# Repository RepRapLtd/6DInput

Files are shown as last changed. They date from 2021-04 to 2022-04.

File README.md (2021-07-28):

# 6DInputs

## A Project to create open-source 3D printed 6 DoF input devices

Note  the plural ('6DInputs' and 'devices') in the headings. We would like several designs to be created here, not just one. Anyone can either contribute a new design or improve or correct an existing one.

### Development

Please fork this repository if you want to contribute, then send a pull request.

Please put your work in one of these folders, as appropriate, or create a folder under which to put the tree of your own work:

 - `Datasheets/` - useful commercial electronic or mechanical devices
 - `Electronics/` - [KiCad](https://www.kicad.org/) circuit designs
 - `Experiments/` - Results of trials and experiments
 - `Ideas/` - Thoughts and brainstorming results
 - `Inspiration/` - Related projects and other online sources of useful information
 - `Mechanics/` - Mechanical designs in [FreeCAD](https://freecadweb.org)
 - `Pictures/` - Generally useful or interestinhg images
 - `Software/` - Software for Arduino, ESP32 etc...

We would like to reserve the folder `RepRapLtd/` for our own work, so we don't get confused...

### Social media

The hashtag for this project is `#os3dmouse`.

### Licence

[GPLv3](LICENCE)

### See also

 - [HyperController](https://github.com/mnesarco/HyperController)

 - [Mighty Mouse](https://github.com/mattogodoy/mighty-mouse)

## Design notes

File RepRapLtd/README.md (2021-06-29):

# An open-source 6 degrees-of-freedom input device

[RepRap Ltd](https://reprapltd.com)

## How far have we got?

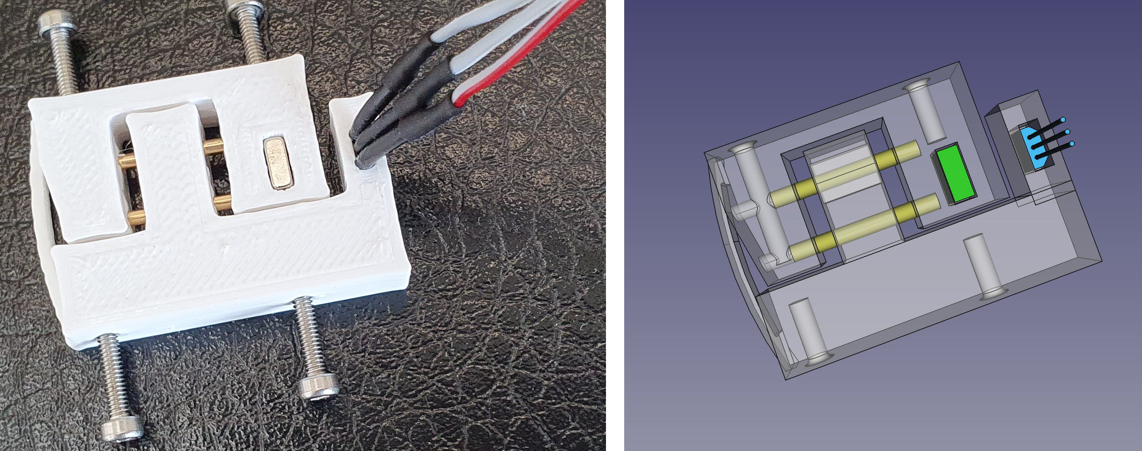
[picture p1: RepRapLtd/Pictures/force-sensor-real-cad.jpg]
Hall force sensor


Based on our [experiments on our original force-sensor design](https://github.com/RepRapLtd/6DInput/tree/main/RepRapLtd/Experiments/ForceSensor) we have created a new force sensor illustrated above.

The actual device is on the left and the FreeCAD design is on the right. It consists of a printed part with two 1.5 mm x 15 mm brass rods inserted into holes to act as sliders. On the right the magnet is shown green, and the Hall sensor is blue. The curved part at the left end of the sensor is a printed spring. The four holes in the sides allow self-tapping M2 screws to be used to attach the force sensor to whatever is pushing and pulling it. The top left screw is longer than the others as it also retains the brass rods.

The FreeCAD design is [here](https://github.com/RepRapLtd/6DInput/tree/main/RepRapLtd/Mechanics/force-sensor-V1.FCStd).

Once again, the magnets [were these](https://www.amazon.co.uk/gp/product/B00TACH0P2), and the Hall sensors were OH49E s.

This design has the following advantages:

 - It has just one integrated printed part,
 - It gives true parallel motion, with no other movement or twist possible, and
 - The additional components are cheap and easy to obtain anywhere.

## Experiments

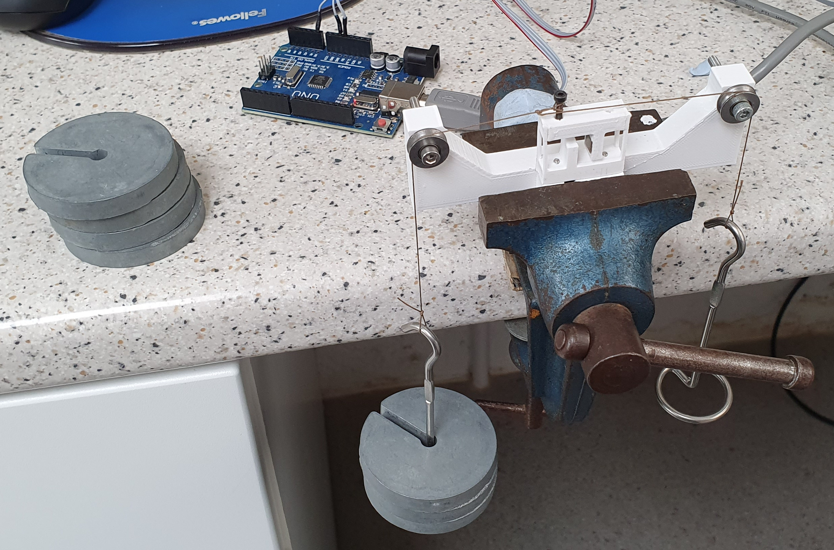
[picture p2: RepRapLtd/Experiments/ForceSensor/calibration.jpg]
force sensor test


We used a calibration jig based on our design for our first calibration experiments illustrated above. The FreeCAD file for the latest jig is in [here](https://github.com/RepRapLtd/6DInput/tree/main/RepRapLtd/Mechanics/calibration-jig.FCStd).

Here is the result of loading and unloading the device:

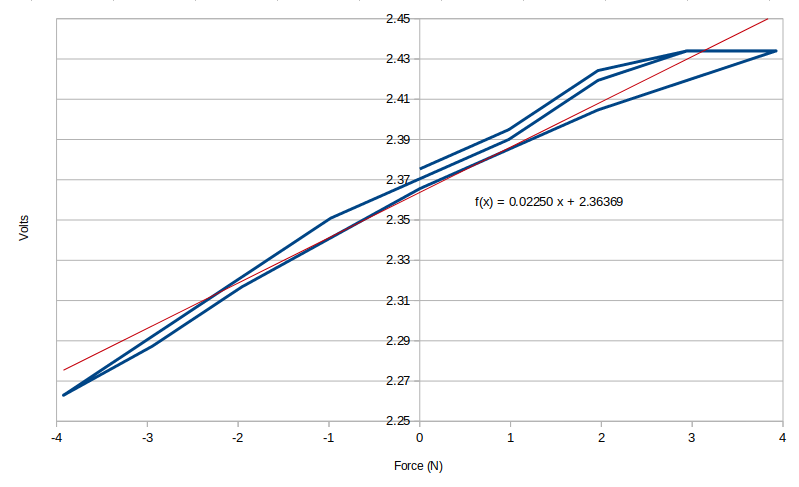
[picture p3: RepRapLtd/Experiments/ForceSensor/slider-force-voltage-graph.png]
test graph


As in our previous experiments, there is a certain amount of hysteresis, as would be expected with a plastic spring. But as you will see this does not impede the performance of the sensor. The red line is the least-squares linear fit, which has the equation shown.

We made two more sensors, giving us three in total. Then we wrote a Python program to read them and to use their output to rotate a cube about the *X, Y* and *Z* axes in 3D on the screen. This worked, and the sensor felt good in use; letting go of the sensors stopped the cube moving; pushing and pulling rotated the cube in all directions; and the harder the push or pull the faster it moved.

There is a video of this working [here](https://github.com/RepRapLtd/6DInput/tree/main/RepRapLtd/Pictures/os3dmouse.mp4) and here is a still from that:

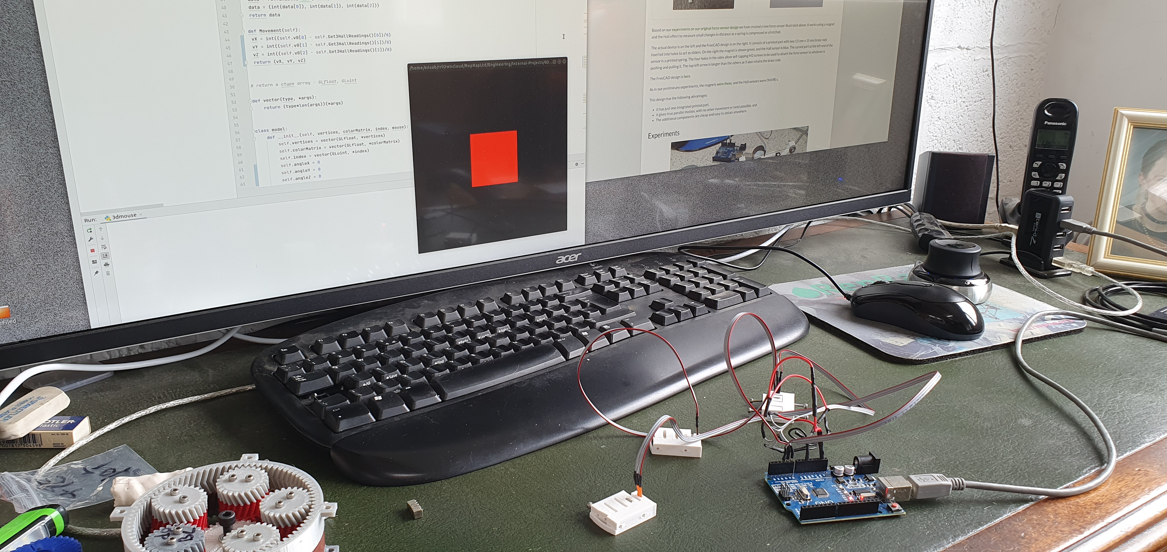
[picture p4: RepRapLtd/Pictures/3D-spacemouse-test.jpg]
1D animation


The Python program is [here](https://github.com/RepRapLtd/6DInput/tree/main/RepRapLtd/Software/3DGraphics/3dmouse.py) and the Arduino program that reads the Hall sensor and talks to the Python program is [here](https://github.com/RepRapLtd/6DInput/tree/main/RepRapLtd/Software/ArduinoHallReader/ArduinoHallReader.ino).

## Update

We realised from the success of this that it would be easy to design a 2D joystick that used the same principles.  This is the result:

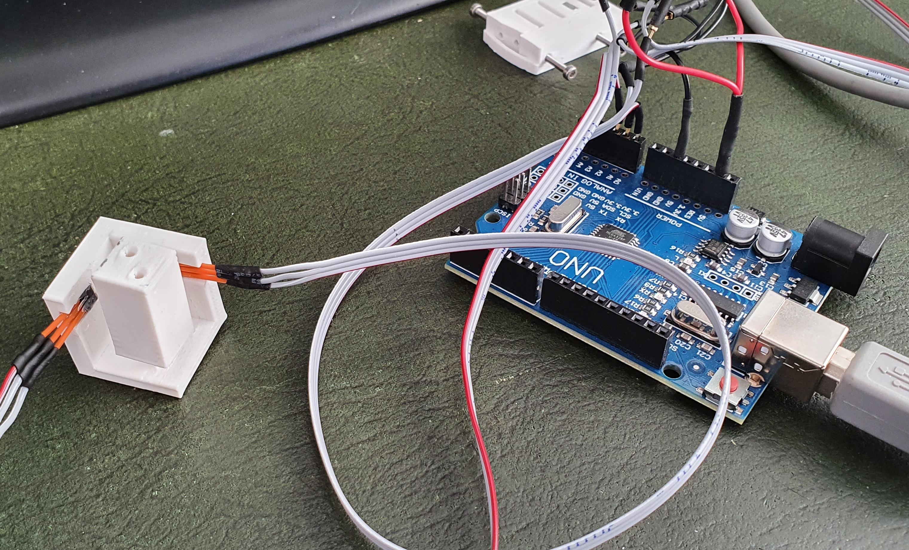
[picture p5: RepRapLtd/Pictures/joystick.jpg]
joystick


And here is the FreeCAD design (which is [here](https://github.com/RepRapLtd/6DInput/tree/main/RepRapLtd/Mechanics/2D-joystick-V1.FCStd) in the repository):

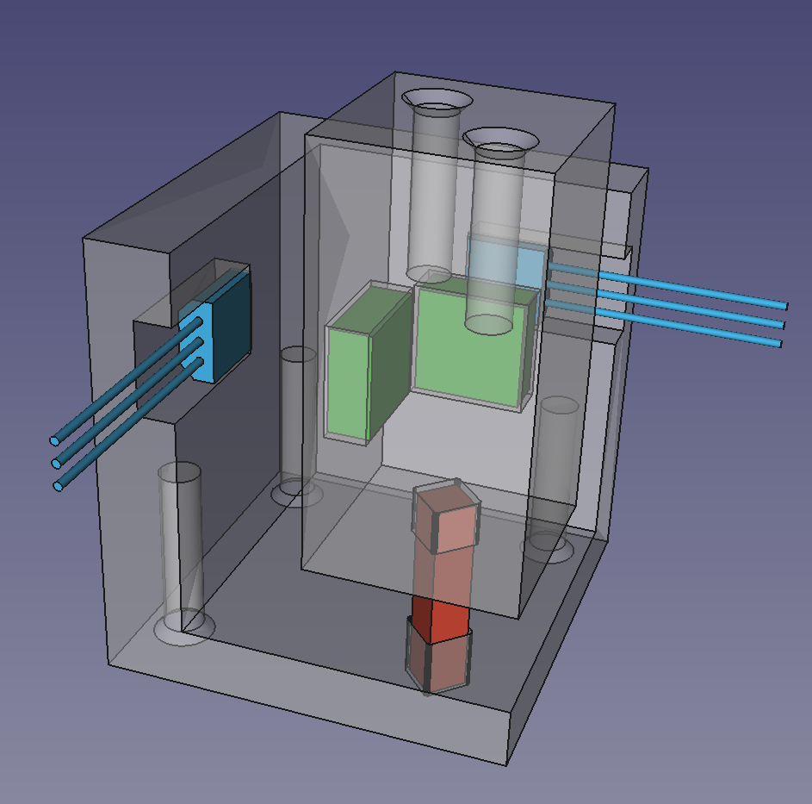
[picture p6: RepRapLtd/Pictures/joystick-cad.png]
cad joystick


Once again the magnets are green and the Hall sensors are blue.  The central block has a square spring attaching it to the base (red for clarity, but printed like the other two parts).  The holes are for self-tapping M2 screws to attach each part of the device to a handle or a solid base.

If you make one glue the magnets in (Araldite, not cyanoacrylate) with the same pole facing outwards from the sprung block. This is tricky because the fields pull them the other way round and they tend to flip over. Force them right and clamp them while the glue sets.

The device connected to the Python program without modifying that (though it has now been updated to use numpy vector arithmetic for neatness and brevity). It worked well, allowing the cube to be tumbled on the screen as in the video above.

This joystick may form part of the final open-source 3D mouse, but it may also be useful to people in its own right as it is very easy to print and the cost of the components is very small.

## Update 2

We have now added rotation about Z to that to create a device that does all possible rotations.

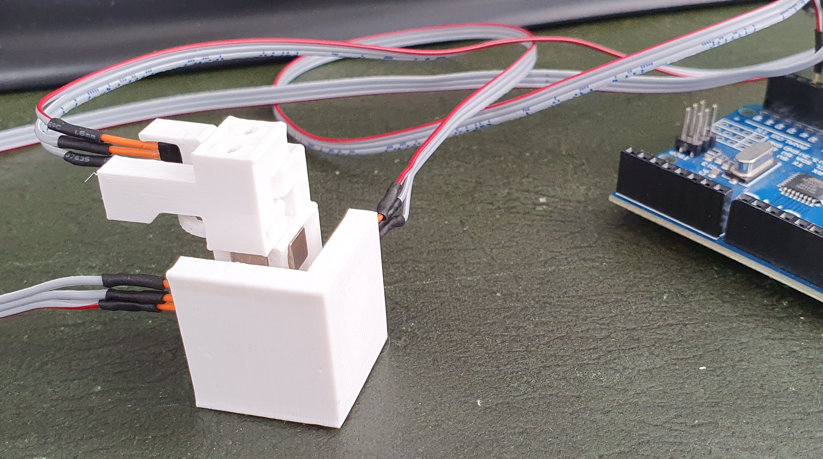
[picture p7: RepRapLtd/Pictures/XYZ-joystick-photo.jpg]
XYZ joystick


And here is the FreeCAD design (which is [here](https://github.com/RepRapLtd/6DInput/tree/main/RepRapLtd/Mechanics/XYZ-joystick-V1.FCStd) in the repository):

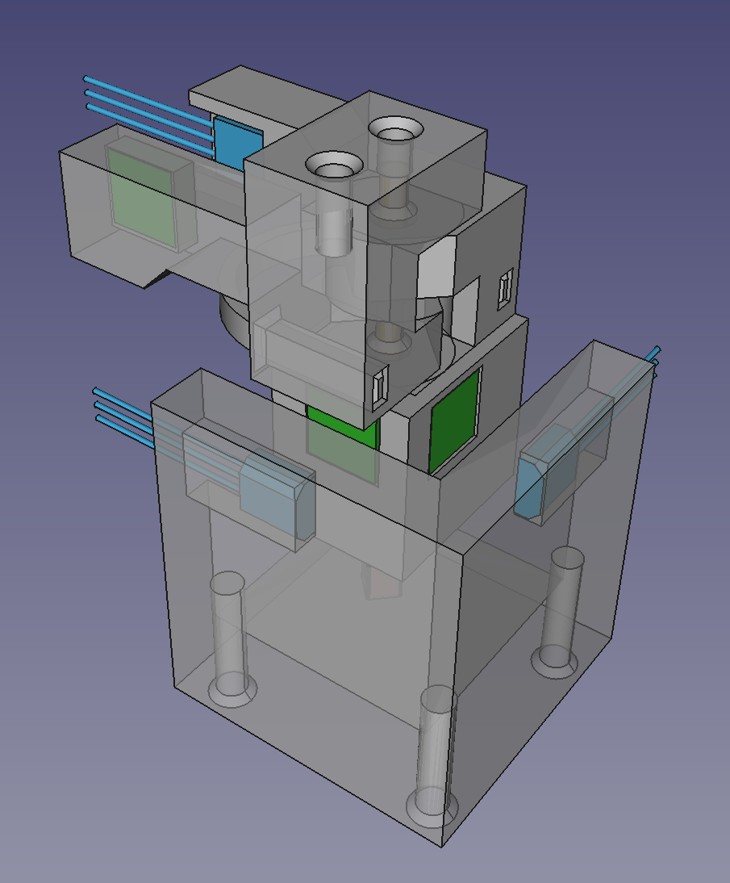
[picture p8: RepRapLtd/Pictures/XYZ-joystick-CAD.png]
XYZ cad joystick


The two holes in the top are for self-tapping M2 screws to attach the device to a handle. The base will screw into the device that detects X, Y and Z translations. The FreeCAD design is here.

There is a video of the device working [here in the repository](https://github.com/RepRapLtd/6DInput/tree/main/RepRapLtd/Pictures/XYZ-joystick.mp4).

## Update 3

Encouraged by that we decided to barge ahead and add three translation axes to the three rotations that worked so nicely. "This won't work because of crosstalk and because it'll have forces too off-centre," we thought. "But we'll do it anyway."

And we were right. Don't build this device...

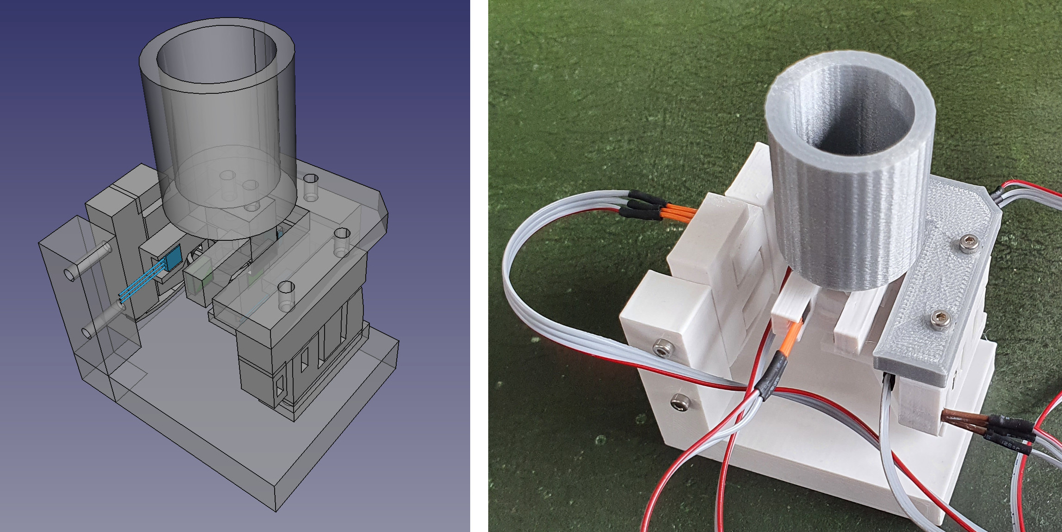
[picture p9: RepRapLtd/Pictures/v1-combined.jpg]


On the left is the CAD design, and on the right the built device. We added three of our translation sensors at the very top of this document to the working rotation joystick above. They all had to be chained, of course - the forces had to be transmitted from the handle (the cylinder on top) through each axis in turn to the fixed base.

The joystick continued to work, but the device was stiff and inacurate in translation measurement, as we had predicted.

The reason we made it even though we thought it might not work was because it has a separate sensor for each of the six types of translation and rotation movement that we need to measure: *X, Y, Z, Rx, Ry,* and *Rz*. This (if it HAD worked) would make the analysis and transmission of the six signals very easy.

But it is now obvious that we need to make a combined device with very simple mechanics, but where we have to unravel the separate signals we want using software because each sensor will be responding to all the inputs (allbeit differently in each case). Here is the next design:

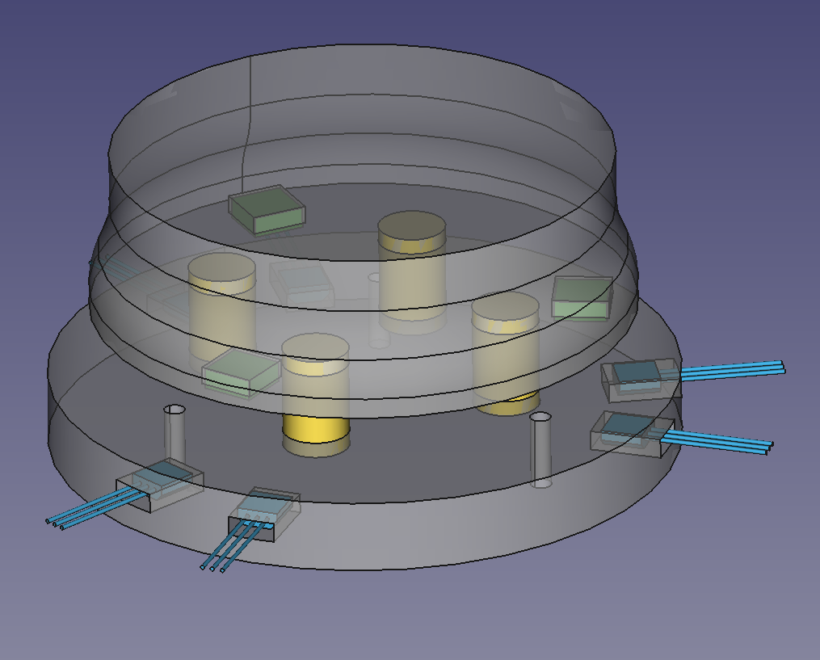
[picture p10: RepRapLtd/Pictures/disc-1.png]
disc design


The magnets are green and the sensors blue. The yellow cylinders are springs that allow the top handle to be moved with all six degrees of freedom. Clearly any movement will produce a change in the output of all the sensors, so this has to be disentangled. We could take the lazy way out and throw a small neural network at the problem, which would probably work. But initially we will try to be a bit more analytical and create a direct mapping from the six input signals to the six output signals required by vector analysis in 6D space.

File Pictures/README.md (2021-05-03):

Place for all general-purpose images for the project.  Specific images (for example SVGs from PCB designs) should go with the design (in that case in the Electronics folder).

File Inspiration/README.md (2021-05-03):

## A place for related and inspirational DIY 6D input devices and videos

### Complete designs

1. Similar to SpaceMouse in design:
   - [Mighty Mouse](https://github.com/mattogodoy/mighty-mouse) by [Matias Godoy](https://github.com/mattogodoy). Identifies the device to the host as a USB mouse.
   - [Ahmsville dial v2](https://www.hackster.io/ahmsville/ahmsville-dial-v2-a38b17) 5 axis space navigator by [Ahmed Oyenuga](https://www.hackster.io/ahmsville). A compact and configurable design for joystick + MPU + encoder, with optional macro keypad. [Video](https://www.youtube.com/watch?v=yGbshYLfDnc) here, and all design files and firmware are on [Ahmed's Github](https://www.youtube.com/watch?v=yGbshYLfDnc) (different repositories).
   - [CAD-Mouse](https://www.thingiverse.com/thing:260830) by [Samuel Kranz](https://www.thingiverse.com/secures/designs) on Thingiverse. A 3D printed DIY joystick with a rotary encoder on top. Files can be found in [Samuel's Github repository](https://github.com/secures92/CADMouse), as well as the firmware for an Arduino HID device (ATMega32U4 ?) and custom Windows driver.
   - [tams_printed_ft](https://github.com/TAMS-Group/tams_printed_ft) - "Low-cost 3D printed force-torque sensors, including ROS drivers, CAD designs, and Arduino firmware.", accompanying a whitepaper in review. Includes a SpaceMouse inspired [OpenSCAD design](https://github.com/TAMS-Group/tams_printed_ft/blob/ec7108c025660944d1c6a2b25e328d470805007b/openscad/spacemouse-9904.scad).
1. Alternative designs
   - [HyperController](https://github.com/mnesarco/HyperController) by [Frank David Martínez](https://github.com/mnesarco). An 8D alternative design, utilizing a couple of thumb joysticks, a few buttons, and potentiometers. Parts combined in a relativley ergonomics layout on a raised armrest.
   - A basic single joystick + single encoder layout, using modifier keys to switch between joystick functions. [Githb repo](https://github.com/soemarko/DIY-Space-Mouse).

### POCs and experimental designs

- [Video](https://youtu.be/71BHSb0jeJg) and [Github repo](https://github.com/BKTRIE/DIY-3D-Mouse) by [BKTRIE](https://www.youtube.com/channel/UC7L7W9u7U4rhSDqpl6tWU_g) of a gyroscope based 3D input mouse. Device is a POC, rotates model by sending mouse commands over USB. Gyroscope is attached to a gooseneck USB lamp mechanically for stabilization, USB device is achieved with a Digispark (ATTiny85).

### Demos without further information

- Francesco Gennari's [Spacemouse 3D Arduino](https://www.youtube.com/watch?v=AJQtHlUEb58) video. No code or 3D models, just video.
- [6D (axsotic)](http://valentinheun.com/portfolio/6d/) by [Valentin Heun](http://valentinheun.com/). This looks like a trackball suspended in a cradle which lets the user interface with the ball from a different angle than usual. Seems to be a concept design.

### Other

- Spacemouse Compact tear-down video by [Thought Bomb Design](https://www.youtube.com/channel/UCY0ro_BXI8MbaN-BvaCWIeA): https://youtu.be/1R7NCH_1UDI

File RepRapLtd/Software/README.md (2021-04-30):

Arduino IDE code in here, plus maybe drivers for Linux, Windows, Mac.

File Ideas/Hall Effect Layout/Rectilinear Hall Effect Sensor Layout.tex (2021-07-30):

\documentclass[]{article}
\usepackage{geometry}
\geometry{margin=1in}

\usepackage{booktabs}
\usepackage{wrapfig}

\usepackage{graphicx}
\usepackage{amsmath,amsfonts,amssymb}
\usepackage{listings}

\usepackage{systeme}

%opening
\title{Layout and Proportionality Calculations for Rectilinear Effect Sensors in 6DOF Manipulator}
\author{David Wright}

\begin{document}
	
	\maketitle
	
	%\begin{abstract}
	
	%\end{abstract}
	
	\section{Background}

\begin{wrapfigure}{r}{0.25\textwidth}
	\begin{center}
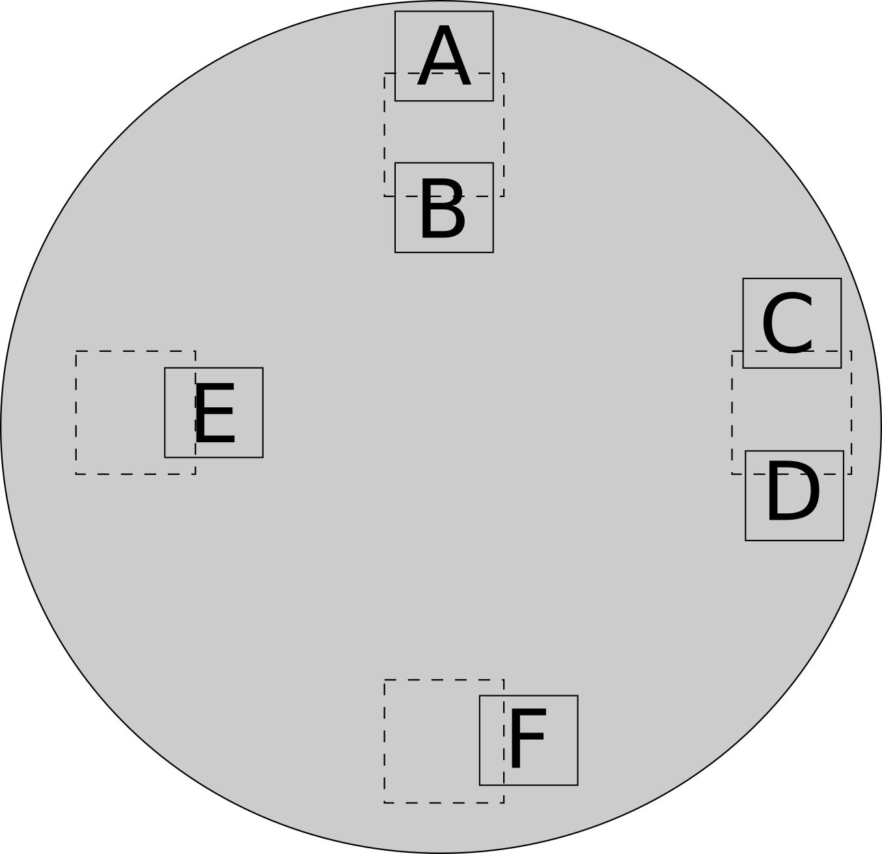
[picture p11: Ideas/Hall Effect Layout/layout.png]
		
	\end{center}
	\caption{Proposed 6-sensor rectilinear layout.}
	\label{fig:ProposedLayout}
	
\end{wrapfigure}
	RepRapPro recently shared a concept for a 6DOF manipulator using three pairs of hall effect sensor arranged at 120 degrees around a circular base. The kinematics of this map the six sensors to the 6 degrees of freedom of the controller. Given my preference for more simple software mapping between sensors and intended input, I propose the following rectilinear sensor layout.

	\section{Proposed Design}
	
	The proposed design uses 6 sensors arranged in pairs or alone at the cardinal points of the control puck base. Dashed lines indicate location of the magnet in the upper moving component. Sensors E and F do not have paired sensors, as the analysis below demonstrates their redundancy. 
	
	The mapping of sensor inputs to translation (T) and rotation (R) is given by the following proportionality matrix. 
		\[
	\begin{bmatrix}
		T_x \\
		T_y \\
		T_z \\
		R_x \\
		R_y \\
		R_z 
	\end{bmatrix} =
	\begin{bmatrix}
		-1 & -1 & -1 & -1 &  1 & 1\\
		1 & -1 & 1 & -1 &  -1 & -1 \\
		-1 & -1 & -1 & -1 &  -1 & -1 \\
		1 & 1 & 0 & 0 & 0 &  -1 \\
		0 & 0 & 1 & 1 &  -1 & 0 \\
		-1 & -1 & 1 &  -1 & -1 & 1 \\
	\end{bmatrix}
	\begin{bmatrix}
		A \\
		B \\
		C \\
		D \\
		E \\
		F \\
	\end{bmatrix}
	\]

	This conversion would just provide the relative proportions of each motion. Scaling to reasonable inputs can be done after this step. 

	\section{First Draft Design and Analysis}
	\begin{wrapfigure}{r}{0.2\textwidth}
	\begin{center}
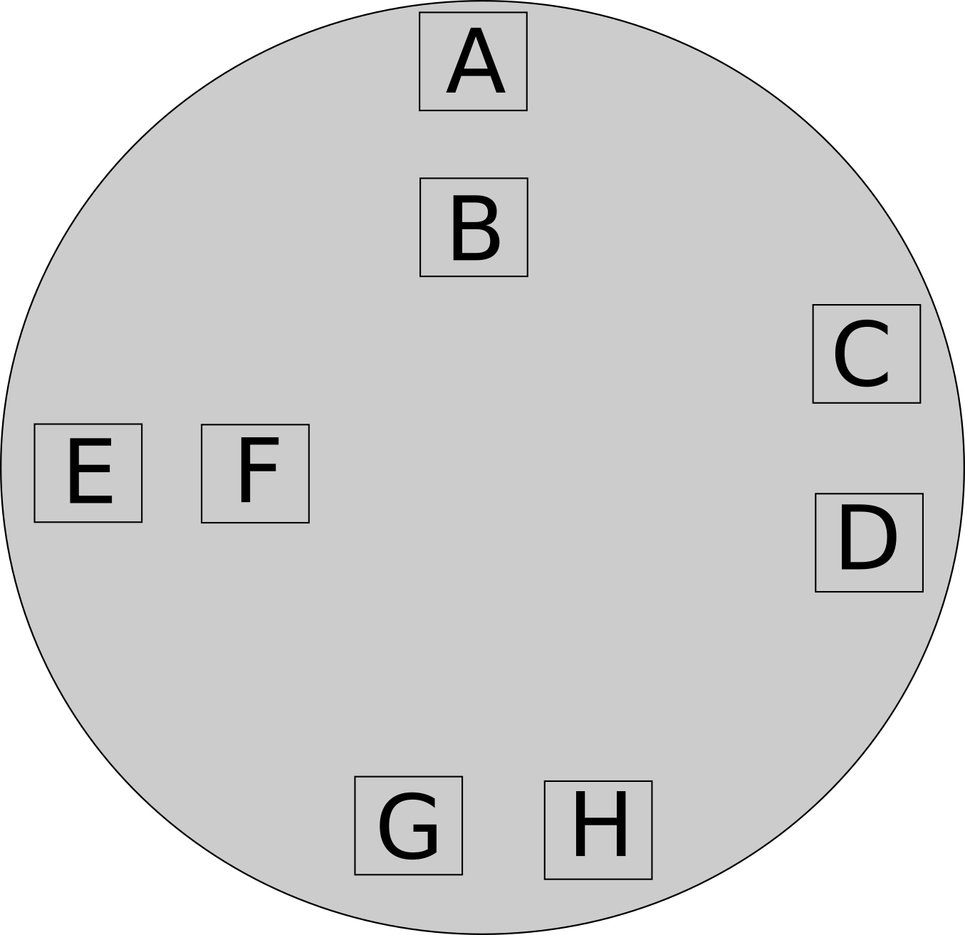
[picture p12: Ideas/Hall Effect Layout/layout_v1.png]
		
	\end{center}
	\caption{Version 1 of the rectilinear layout concept using 8 sensors.}
	\label{fig:LayoutV1}
	\end{wrapfigure}	
	
	The initial design used eight sensors, using pairs at the cardinal points of the circle. The intent was that for both x and y axes, there was a pair of sensors to detect translation and rotation. I assumed that the two additional sensors could be incorporated into the analysis for noise reduction.
	
	To map sensor inputs to desired output, I considered the effect of each direction separately on each sensors response, creating a linear set of equations, shown below. For a given 

	\begin{center}
	\[
		\systeme*{Translate_x=-A-B-C-D-E+F-G+H,
	Translate_y=A-B+C-D-E-F-G-H, 
	Translate_z=-A-B-C-D-E-F-G-H, 
	Rotate_x=A+B+0\cdot C+\cdot D + 0\cdot E + 0\cdot F - G - H, 
	Rotate_y=0\cdot A + 0\cdot B + 0\cdot C - E - F + G + H, 
	Rotate_z=-A-B+C-D-E-F-G+H}
\]		
	\end{center}

	This system of equations converts nicely into a linear algebra conversion, as given below.
	\[
	\begin{bmatrix}
	T_x \\
	T_y \\
	T_z \\
	R_x \\
	R_y \\
	R_z 
	\end{bmatrix} =
	\begin{bmatrix}
		-1 & -1 & -1 & -1 & -1 & 1 & -1 & 1\\
		1 & -1 & 1 & -1 & -1 & -1 & -1 & -1 \\
		-1 & -1 & -1 & -1 & -1 & -1 & -1 & -1 \\
		1 & 1 & 0 & 0 & 0 & 0 & -1 & -1 \\
		0 & 0 & 1 & 1 & -1 & -1 & 0 & 0 \\
		-1 & -1 & 1 & -1 & -1 & -1 & -1 & 1 \\
	\end{bmatrix}
	\begin{bmatrix}
		A \\
		B \\
		C \\
		D \\
		E \\
		F \\
		G \\
		H
	\end{bmatrix}
	\]

	This simplification shows that both inputs E and G are constantly -1 or is not used. From this it follows that they are redundant sensors and not needed for full 6DOF manipulation. 
	
\end{document}

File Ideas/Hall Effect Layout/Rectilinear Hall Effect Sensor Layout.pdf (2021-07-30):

# Layout and Proportionality Calculations for Rectilinear Effect Sensors in 6DOF Manipulator

David Wright

July 29, 2021

## 1 Background

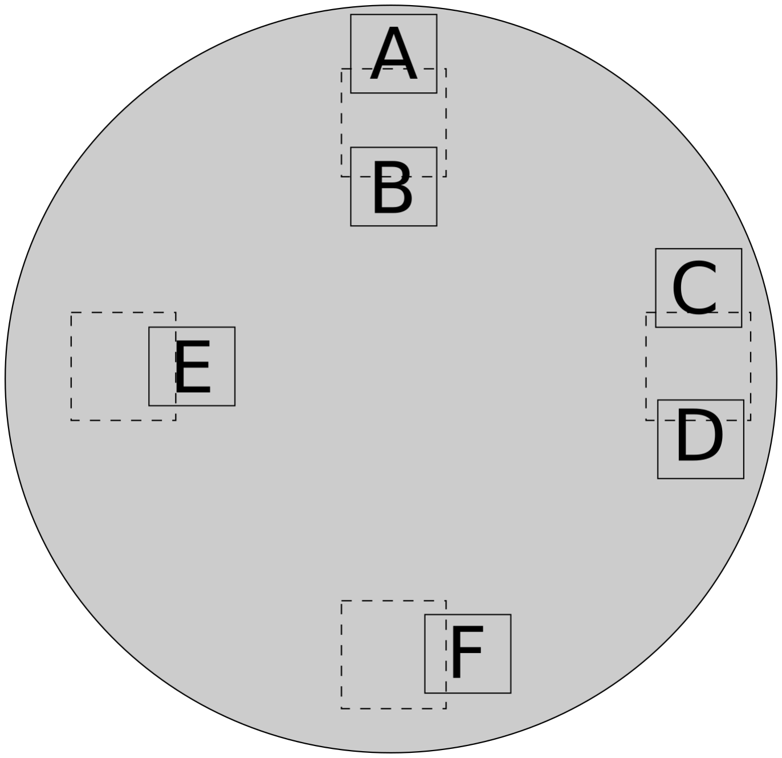
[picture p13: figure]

Figure 1: Proposed 6-
sensor rectilinear layout.

RepRapPro recently shared a concept for a 6DOF manipulator using three pairs of hall effect sensor arranged at 120 degrees around a circular base. The kinematics of this map the six sensors to the 6 degrees of freedom of the controller. Given my preference for more simple software mapping between sensors and intended input, I propose the following rectilinear sensor layout.

## 2 Proposed Design

The proposed design uses 6 sensors arranged in pairs or alone at the cardinal points of the control puck base. Dashed lines indicate location of the magnet in the upper moving component. Sensors E and F do not have paired sensors, as the analysis below demonstrates their redundancy.
The mapping of sensor inputs to translation (T) and rotation (R) is given by the following proportionality matrix.

Tx
Ty
Tz
Rx
Ry
Rz

=

−1 −1 −1 −1 | 1 | 1
1 | −1 | 1 | −1 −1 −1
−1 −1 −1 −1 −1 −1
1 | 1 | 0 | 0 | 0 | −1
0 | 0 | 1 | 1 | −1 | 0
−1 −1 | 1 | −1 −1 | 1

A
B
C
D
E
F

This conversion would just provide the relative proportions of each motion. Scaling to reasonable inputs can be done after this step.

## 3 First Draft Design and Analysis

Figure 2: Version 1 of
the rectilinear layout
concept using 8 sensors.

The initial design used eight sensors, using pairs at the cardinal points of the circle. The intent was that for both x and y axes, there was a pair of sensors to detect translation and rotation. I assumed that the two additional sensors could be incorporated into the analysis for noise reduction.
To map sensor inputs to desired output, I considered the effect of each direction separately on each sensors response, creating a linear set of equations, shown below. For a given

1

T ranslatex = −A − B − C − D − E + F − G + H T ranslatey = A − B + C − D − E − F − G − H T ranslatez = −A − B − C − D − E − F − G − H Rotatex = A + B + 0 · C + ·D + 0 · E + 0 · F − G − H Rotatey = 0 · A + 0 · B + 0 · C − E − F + G + H Rotatez = −A − B + C − D − E − F − G + H

This system of equations converts nicely into a linear algebra conversion, as given below.

Tx
Ty
Tz
Rx
Ry
Rz

=

−1 −1 −1 −1 −1 | 1 | −1 | 1
1 | −1 | 1 | −1 −1 −1 −1 −1
−1 −1 −1 −1 −1 −1 −1 −1
1 | 1 | 0 | 0 | 0 | 0 | −1 −1
0 | 0 | 1 | 1 | −1 −1 | 0 | 0
−1 −1 | 1 | −1 −1 −1 −1 | 1

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
This simplification shows that both inputs E and G are constantly -1 or is not used. From this it follows that they are redundant sensors and not needed for full 6DOF manipulation.

2

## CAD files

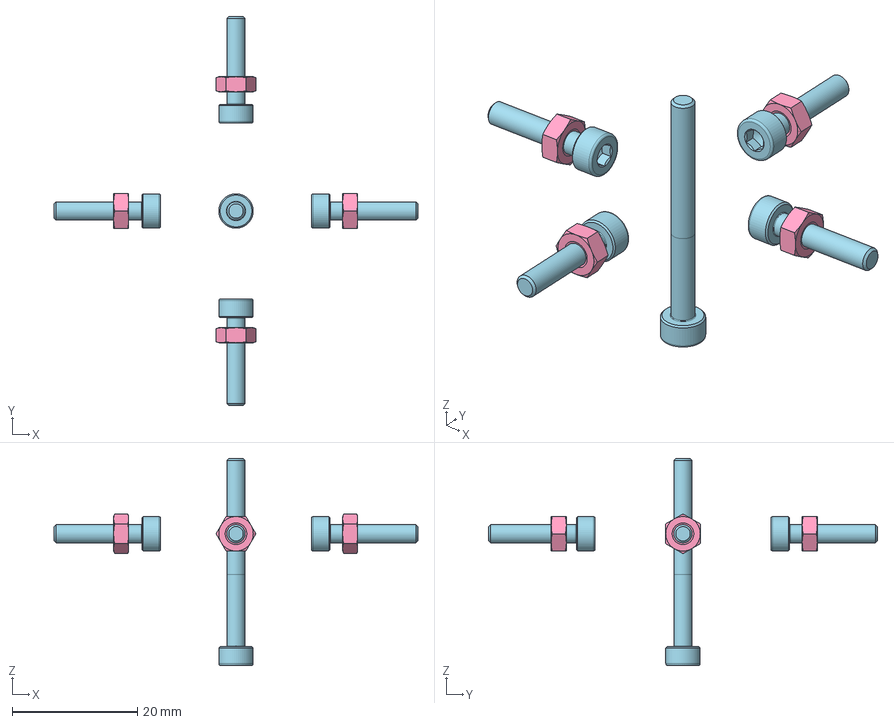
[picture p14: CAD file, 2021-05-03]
Mechanics/Assembly Experiments/3D Printable Joystick Assembly - Magnetic Encoders/6DInput_MagneticEncoder.FCStd
58.0 x 62.0 x 33.0 mm
M3x14-Screw
M3x14-Screw001
M3x30-Screw
M3x14-Screw002
M3x14-Screw003
M3-Nut
M3-Nut001
M3-Nut002
M3-Nut003

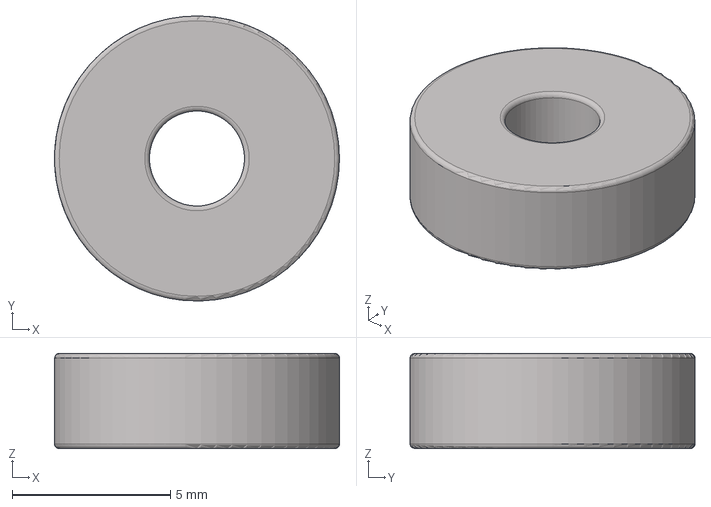
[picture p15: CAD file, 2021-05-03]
Mechanics/Assembly Experiments/3D Printable Joystick Assembly - Magnetic Encoders/Parts/Bearing603Open.FCStd
9.00 x 9.00 x 3.00 mm

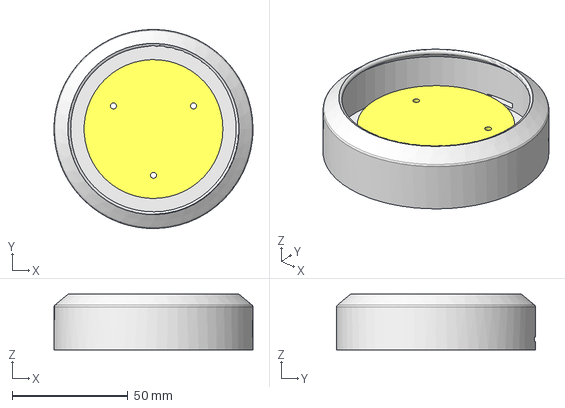
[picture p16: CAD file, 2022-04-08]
RepRapLtd/Mechanics/SM Base.FCStd
86.0 x 86.0 x 24.0 mm
Brass Weight001
Base

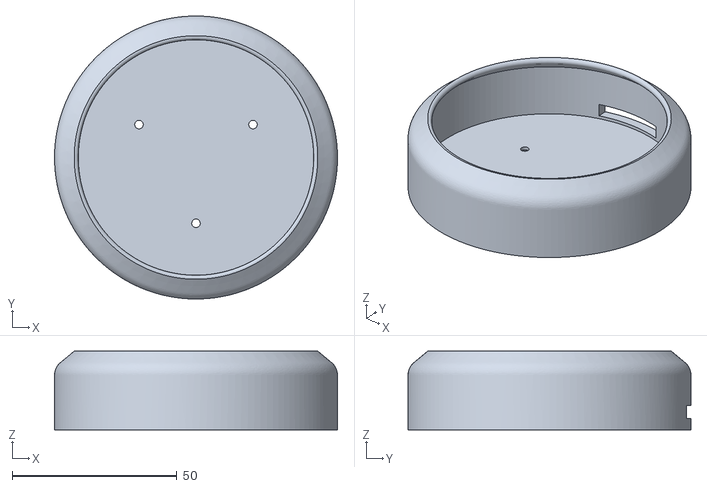
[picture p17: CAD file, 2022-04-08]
RepRapLtd/Mechanics/STLs/SM Base-Base.stl
86.0 x 86.0 x 24.0

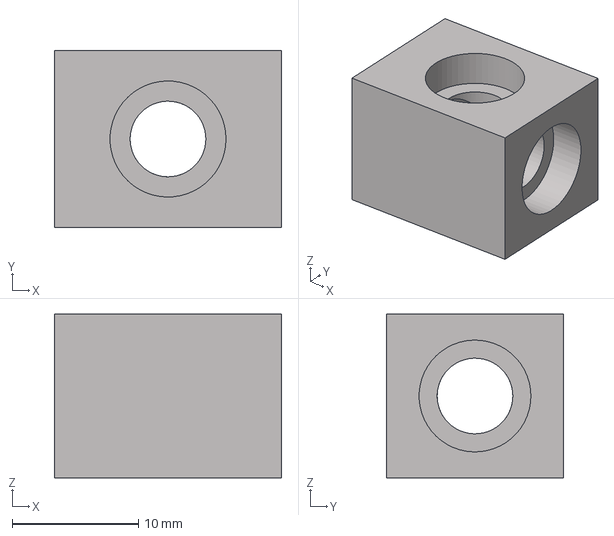
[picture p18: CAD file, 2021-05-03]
Mechanics/Assembly Experiments/3D Printable Joystick Assembly - Magnetic Encoders/Parts/ShaftBearingHousing.FCStd
18.0 x 14.0 x 13.0 mm

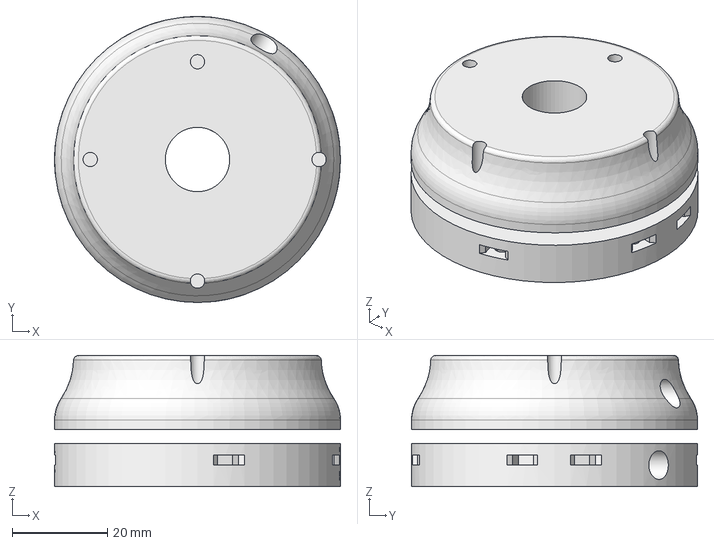
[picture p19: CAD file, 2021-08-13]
RepRapLtd/Mechanics/6DOF-disc-wright.FCStd
60.0 x 60.0 x 27.5 mm
base
handle

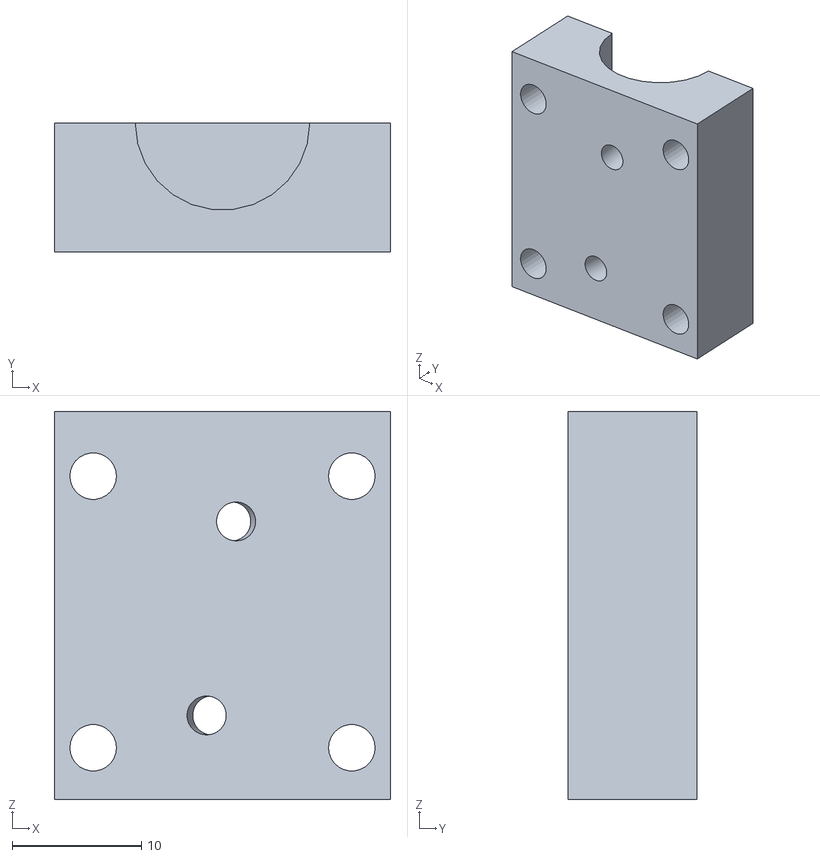
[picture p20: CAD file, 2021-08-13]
RepRapLtd/Mechanics/STLs/silicone-spring-mould-b.stl
26.0 x 10.0 x 30.0

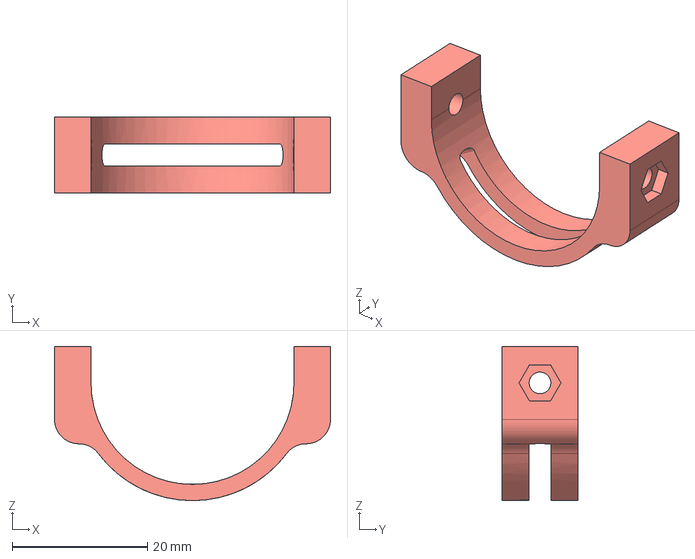
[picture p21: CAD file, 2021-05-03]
Mechanics/Assembly Experiments/3D Printable Joystick Assembly - Magnetic Encoders/Parts/GimbalX.FCStd
40.8 x 11.2 x 22.8 mm

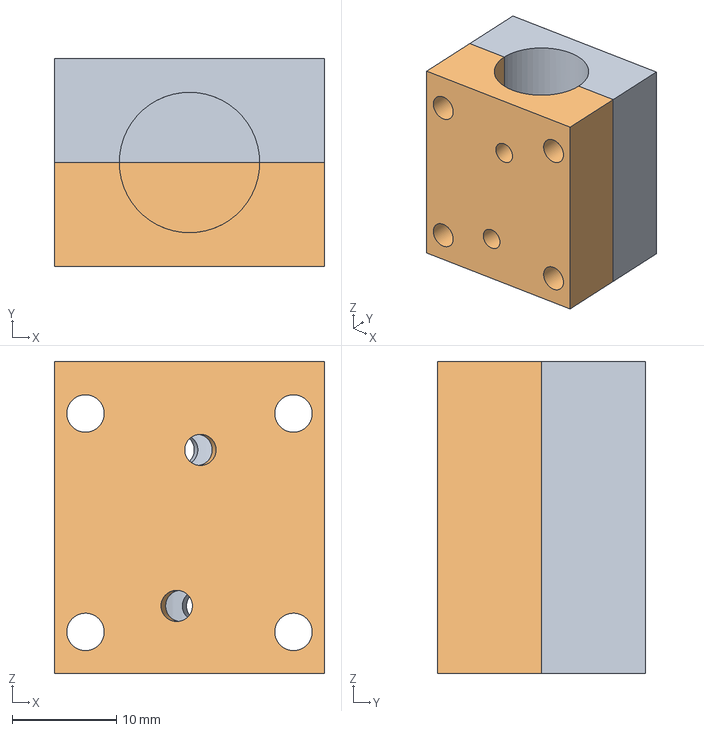
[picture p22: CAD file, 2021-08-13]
RepRapLtd/Mechanics/silicone-spring-mould.FCStd
26.0 x 20.0 x 30.0 mm
mould-a
mould-b

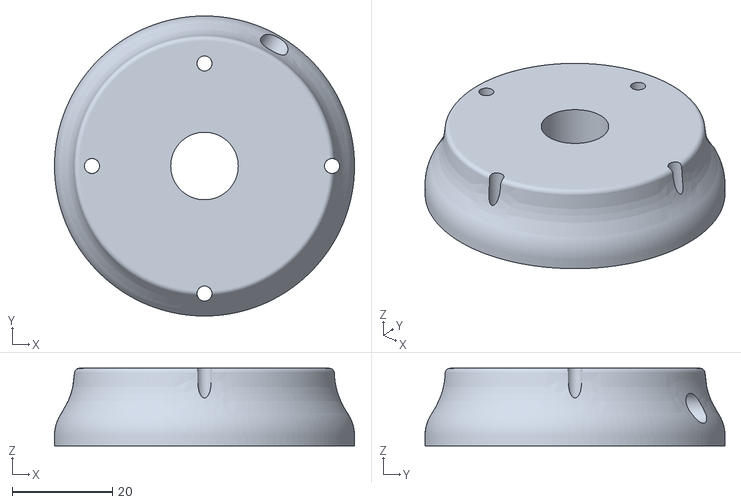
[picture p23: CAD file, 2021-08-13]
RepRapLtd/Mechanics/STLs/6DOF-disc-wright-handle.stl
60.0 x 60.0 x 15.5

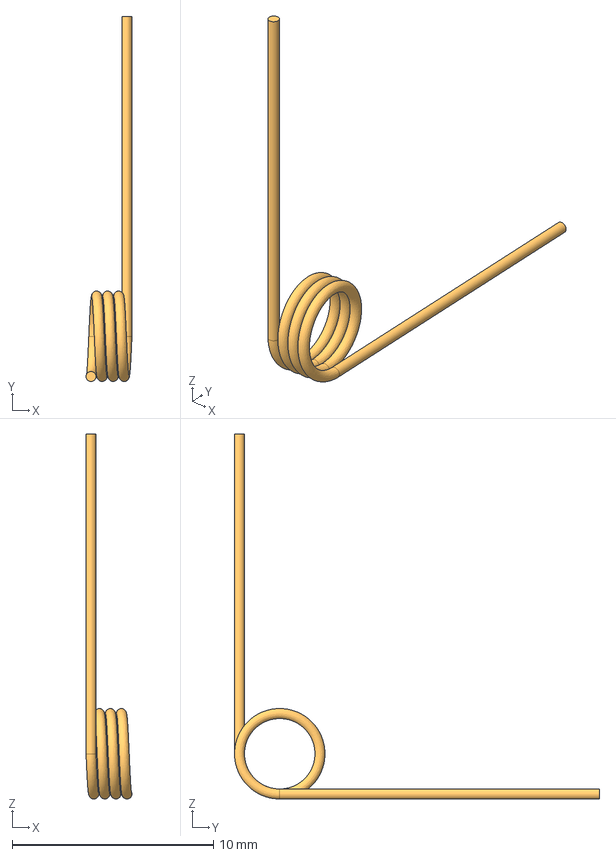
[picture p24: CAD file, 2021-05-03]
Mechanics/Assembly Experiments/3D Printable Joystick Assembly - Magnetic Encoders/Parts/TorsionSpring.FCStd
2.29 x 18.1 x 18.1 mm

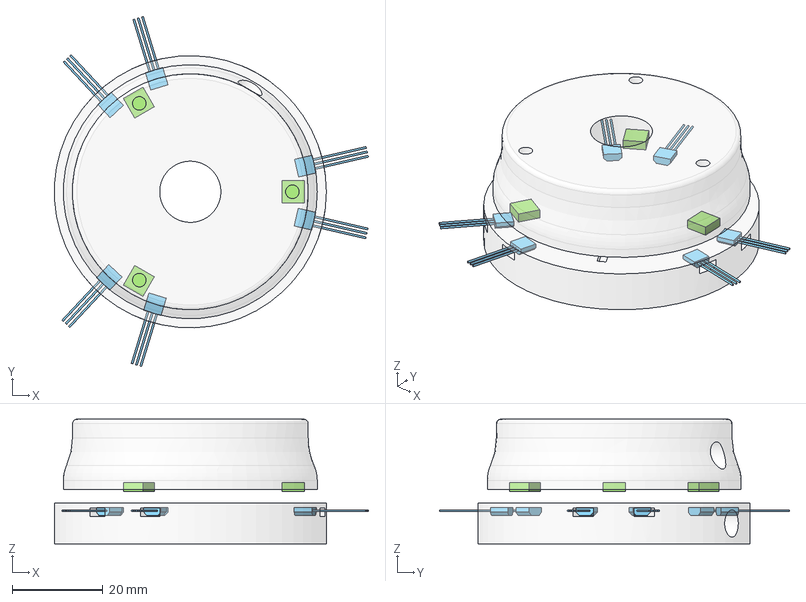
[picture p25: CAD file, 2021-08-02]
RepRapLtd/Mechanics/6DOF-disc.FCStd
69.2 x 77.2 x 27.5 mm
sensors
magnets
handle
base

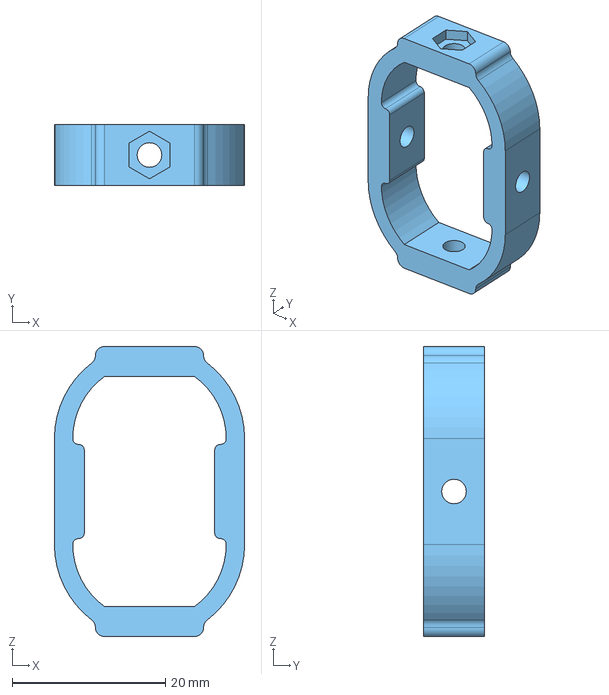
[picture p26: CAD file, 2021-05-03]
Mechanics/Assembly Experiments/3D Printable Joystick Assembly - Magnetic Encoders/Parts/GimbalY.FCStd
24.8 x 8.00 x 37.8 mm

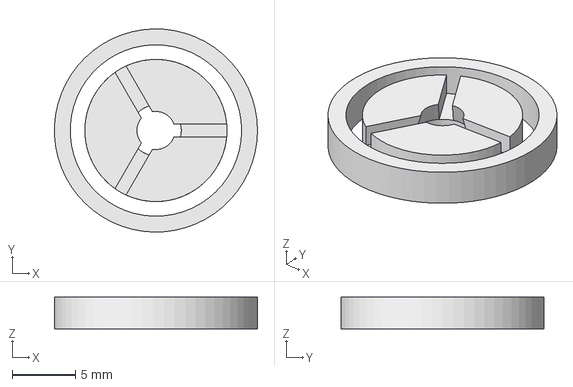
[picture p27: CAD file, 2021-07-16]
RepRapLtd/Mechanics/spring-clamp.FCStd
16.0 x 16.0 x 2.50 mm

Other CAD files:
RepRapLtd/Mechanics/STLs/silicone-spring-mould-a.stl
RepRapLtd/Mechanics/STLs/6DOF-disc-wright-base.stl
Mechanics/Assembly Experiments/3D Printable Joystick Assembly - Magnetic Encoders/Parts/AS5247UAdapterBoard.FCStd
RepRapLtd/Mechanics/OS3Dmouse-V1.FCStd
Experiments/Geometry Tester/Geometry Tester.blend
Mechanics/Assembly Experiments/3D Printable Joystick Assembly - Magnetic Encoders/Parts/Dial.FCStd
Mechanics/Assembly Experiments/3D Printable Joystick Assembly - Magnetic Encoders/Parts/DiametricMagnet8x2.5mm.FCStd
Mechanics/Assembly Experiments/3D Printable Joystick Assembly - Magnetic Encoders/Parts/GimbalMount.FCStd
RepRapLtd/Mechanics/2D-joystick-V1.FCStd
RepRapLtd/Mechanics/6DOF-cones.FCStd
RepRapLtd/Mechanics/Hall-ring-experiment-holder.FCStd
RepRapLtd/Mechanics/Legacy/force-displacement-sensor-V2.FCStd
RepRapLtd/Mechanics/Legacy/force-displacement-sensor.FCStd
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

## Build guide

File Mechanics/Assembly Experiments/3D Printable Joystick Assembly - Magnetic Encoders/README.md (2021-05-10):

# Assembly Information
This is a simple concept model to explore the feasibility of modeling the entire joystick assembly with an infinitely "scrolling" dial.

**This design is not complete and will not function in its current state.**

Magnetic Angular Position sensors were used in this example, but are interchangeable with hall effect sensors.

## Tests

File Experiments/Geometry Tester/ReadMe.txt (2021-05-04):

This is a test script attached to a blender file which outputs the distance between a magnet and the sensors. This could be used to simulate designs.

While made in blender 2.82, the script may be able to be adapted to work with FreeCADs scripting too.

How to use:
- open the file in blender
- jump over to the scripting tab and make sure you have "geometryTestScript" selected.

- !update the filepath with one for your computer!

- hit the play button at the top of the pain
- The distances will update on every new frame of animation

TODO:
- Make distance have an R^2 fall off, like in real life.
- Use matplotlib to output a graph directly, rather than having to use excel on the CSV.
- Make it easier to adapt to new designs with different parts etc.
- Parent the parts together to make it easier to use.

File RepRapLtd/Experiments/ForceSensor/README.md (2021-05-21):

# A simple force sensor using the Hall effect

Adrian Bowyer

## The Idea

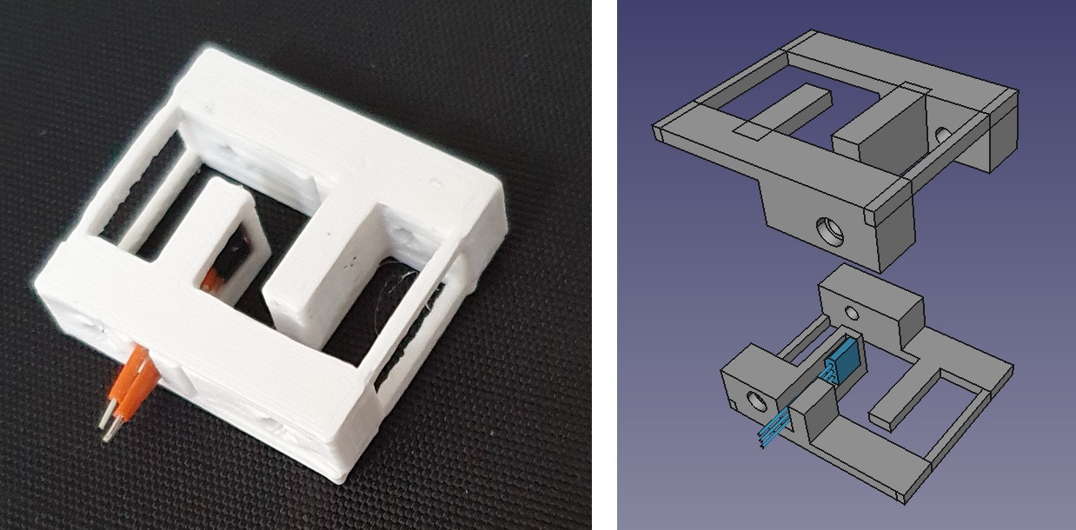
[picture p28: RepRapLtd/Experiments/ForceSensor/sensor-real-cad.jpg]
Hall force sensor


Based on our [experiments in measuring positions in space](https://github.com/RepRapLtd/6DInput/tree/main/RepRapLtd/Experiments/HallCalibration) using Hall sensors we decided to make a simple force sensor.

To start with, we used our previous experimental setup to plot a graph of voltage (in Arduino analogue to digital converter readings; [0, 1023]) against the displacement that generated that voltage:

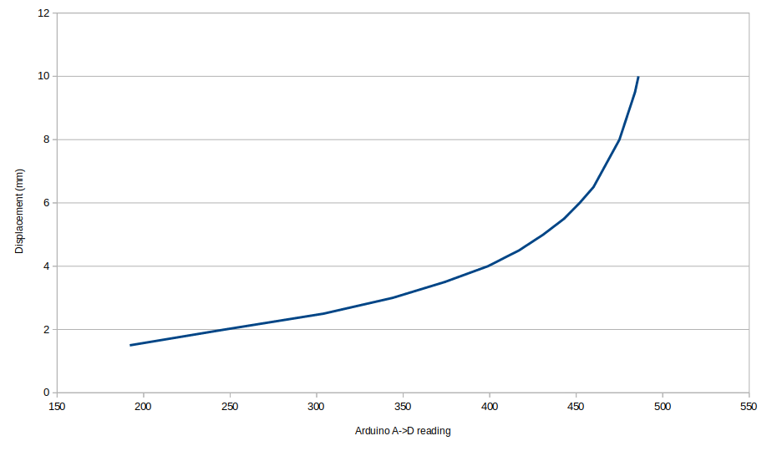
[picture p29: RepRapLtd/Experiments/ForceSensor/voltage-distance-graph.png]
voltage vs. distance


Once again, the magnets [were these](https://www.amazon.co.uk/gp/product/B00TACH0P2), and the Hall sensors were OH49E s. The voltage is the dependent variable, obviously, but we plotted it on the *X* axis because in general you would want to know the displacement given a voltage reading.

Based on this graph we decided to make a system with a 5mm gap between the magnet and the sensor at zero force, with displacements of +/- 1mm for forces of 5N or so.

The picture at the top shows the resulting design for the sensor. On the left is a photograph of it assembled, and on the right is an exploded view of the two printed parts that make it up. It is about 25mm square and 8 mm deep.

You can see the three wires of the Hall sensor (orange in the photograph; blue in the CAD design). The magnet is embedded in the opposite projection. Here is a CAD picture showing it the other way up; the magnet is green:

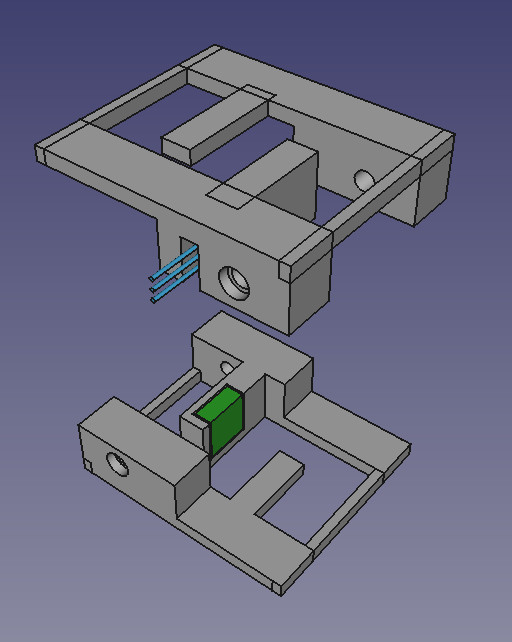
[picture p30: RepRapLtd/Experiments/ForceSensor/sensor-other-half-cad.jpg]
magnet in sensor


The four thin rectangular sections form the spring. The four small circular holes are mounting holes for self-tapping M2 screws.

The reason we made it in two halves was so that the four spring elements could be printed flat against the printer's bed without support. To assemble it the magnet and the Hall sensor are glued into their respective halves with superglue, and the two halves are then glued together.

The [CAD file is here](https://github.com/RepRapLtd/6DInput/tree/main/RepRapLtd/Mechanics) in the file force-displacement-sensor-V2.FCStd.

## Experiments

force sensor test

We designed a test jig for the device (it's in the same CAD file) that allows it to be loaded in either direction by hanging weights on two threads running over two pulleys. The Hall voltages were logged by an Arduino, which you can also see.

Here is the resulting force-voltage graph showing a full cycle starting with 700g on the left thread, reducing that to 0g, adding the weights to the right thread, and then reversing that entire sequence:

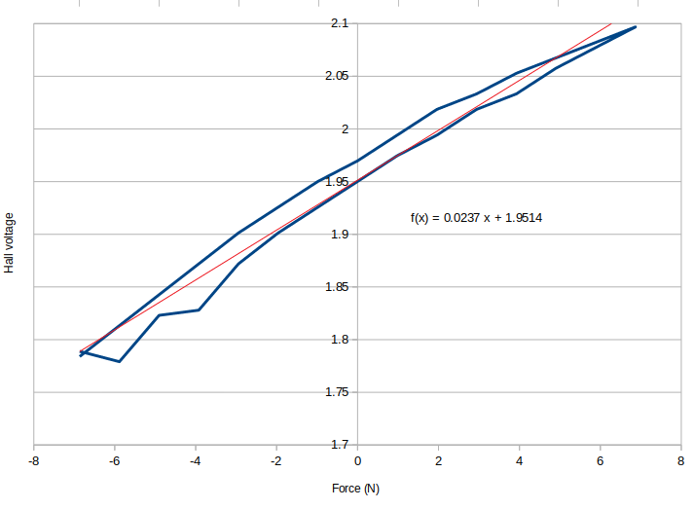
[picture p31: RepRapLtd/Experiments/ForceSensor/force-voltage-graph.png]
test graph


As the springs are plastic some hysterisis would be expected, and you can see that has occured. The red line and the formula are a best-fit linear approximation to the results.

## Application

Three of these (or something similar) stacked would be needed to measure the three translational forces in a 6-degree-of-freedom printed spacemouse. A design for measuring torque would also be needed for the three rotations.

## What next?

We have reduced the zero-force gap between the Hall sensor and the magnet to 3mm in the latest version in the CAD file. If you look at the top graph above you will see that this should increase both linearity and sensitivity.

We will design a similar device to measure torque.

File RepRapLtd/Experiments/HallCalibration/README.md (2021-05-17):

# Calibrating Hall Sensors Automatically using a RepRap Machine

Adrian Bowyer

## The Idea

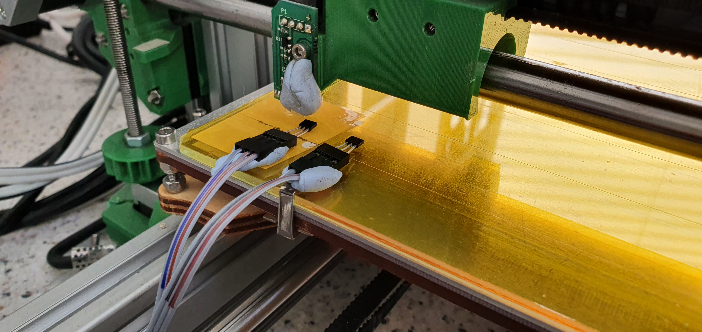
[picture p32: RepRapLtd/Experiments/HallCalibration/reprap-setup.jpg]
RepRap Setup


What we wanted to know is: can we digitise 6-degree-of-freedom movement by having that movement move magnets around near Hall-effect sensors?

This experiment tested a two-dimensional version of that idea.  It did so by attaching a small magnet to the carriage of a RepRap machine and two Hall sensors to its bed, then running a Python program to drive the head about while monitoring the voltages generated by the Hall sensors.

The magnets [were these](https://www.amazon.co.uk/gp/product/B00TACH0P2), and the Hall sensors were OH49E s.

The picture above shows the arrangement - two sensors, H<sub>0</sub> and H<sub>1</sub>, were attached to the bed using Blu Tack 15 mm apart on the X axis at *x* = 5 and *x* = 20, and the magnet was attached to the carriage, again with Blu Tack.

The Python program ([which is in this repository here](https://github.com/RepRapLtd/6DInput/tree/main/RepRapLtd/Software/CalibrationMapPython)) moved the RepRap machine from *x* = 0 to *x* = 25 in steps of 1mm taking readings from the Hall sensors at each step. It then moved up in *z* by 1mm and repeated the *x* movements, to a maximum of *z* = 10.

The Hall readings were done by an Arduino Uno. The program for that is [in this repository here](https://github.com/RepRapLtd/6DInput/tree/main/RepRapLtd/Software/CalibrationMapArduino).

There is a video of the experiment in progress in this directory: running-experiment.mp4 .

## 2 Dimensional Results

The raw integer values of the Hall voltages, H<sub>0</sub> and H<sub>1</sub> logged by the Arduino were summed and differenced as in this idea from a few days ago:

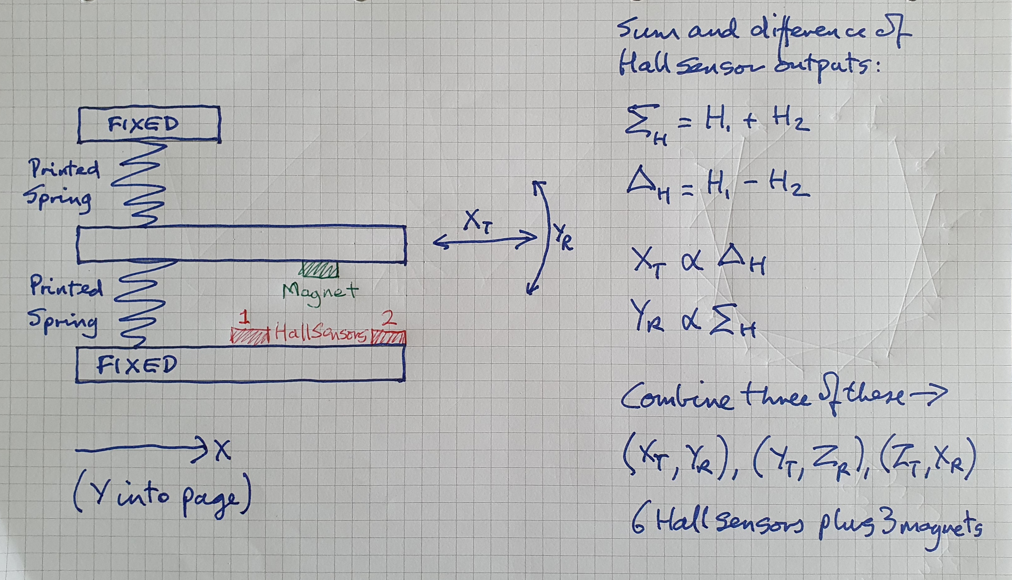
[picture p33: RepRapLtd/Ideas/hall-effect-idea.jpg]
Sum Diff Idea


The idea behind this was that the sum should be roughly proportional to movement in *z* (*y* on the original idea sketch) and the difference should be roughly proportional to movement in *x*.

Here are the matrices of sum and difference calibration values plotted by GNUPlot:

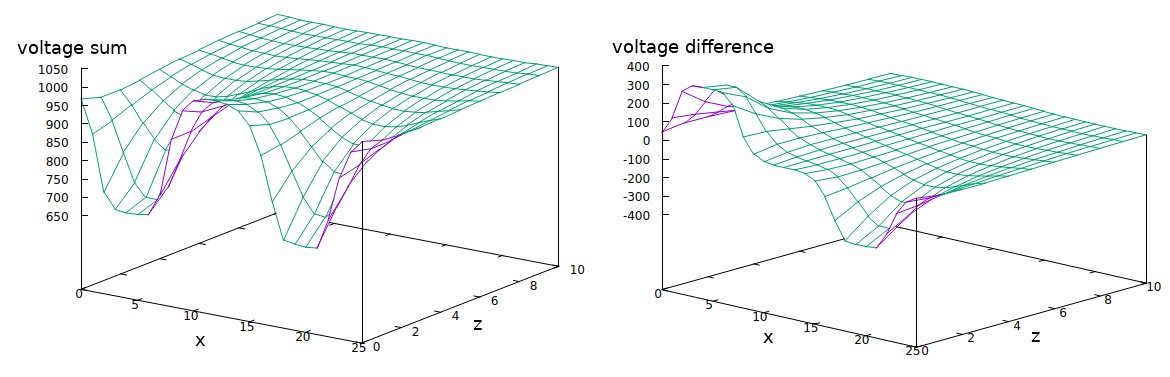
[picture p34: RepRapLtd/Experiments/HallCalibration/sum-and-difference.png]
Sum and Diff


Remember the Hall sensors were at (5,0) and (20,0).

Then the Python program repeated the movements, but this time attempted to calculate the *x* and *z* coordinates that the magnet was at from the Hall readings by comparing the Hall sum and difference values to the two calibration matrices illustrated above. It used simple Euclidean distance in the sum/difference space to find the closest corresponding *x* and *z* values.  It got most right (zero Euclidean distance).  Here is a plot of the errors:

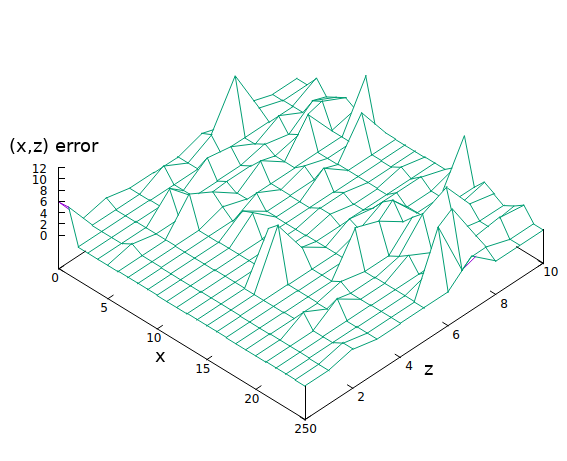
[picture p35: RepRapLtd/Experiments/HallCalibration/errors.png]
errors


It's clear from this that we are being a bit ambitious about range. There are flat areas in the sum and difference maps that will lead to uncertainty about the position of the magnet in space. So we repeated the experiment with the hall sensors 10 mm apart and with a *z* range of 5mm. Here is the error map:

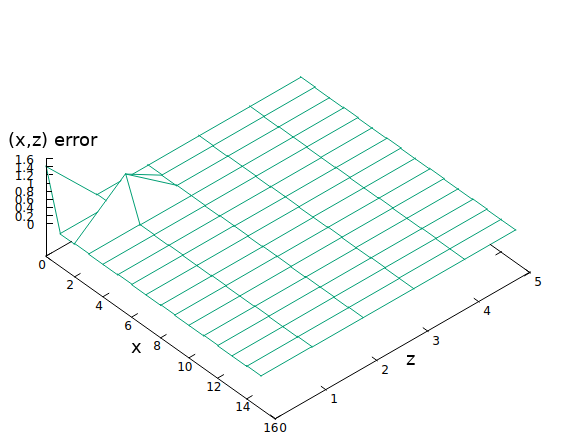
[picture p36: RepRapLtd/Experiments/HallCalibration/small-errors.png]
small errors


The Hall sensors were at (2.5, 0) and (12.5, 0). As you can see the positioning was perfect in between the two sensors, with zero error, and there were small errors just outside the range.

## 3 Dimensional Results

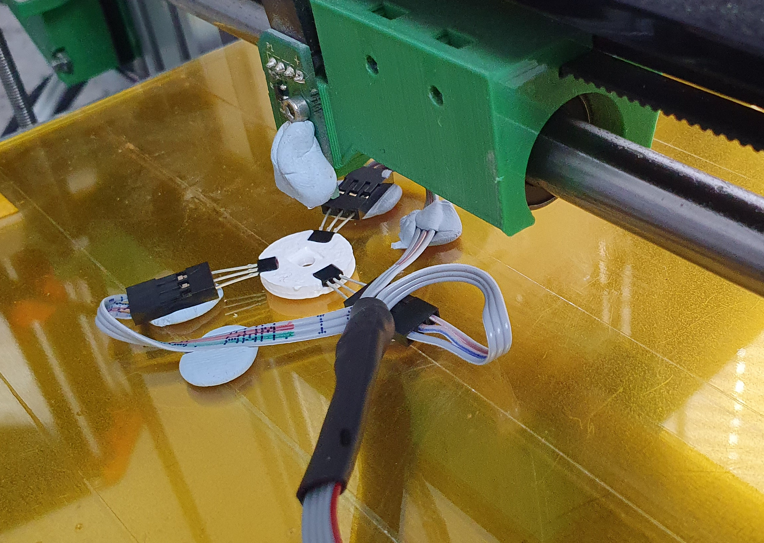
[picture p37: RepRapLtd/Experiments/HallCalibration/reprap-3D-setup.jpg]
RepRap 3D Setup


The next experiment was to attempt to find the position of the magnet in a three-dimensional (*x, y, z*) volume, as opposed to a two-dimensional (*x, z*) plane. For this we attached a ring of three Hall sensors to the RepRap's bed at 120<sup>o</sup> as shown above. The centres of the sensors were on a circle of radius 6mm. The magnet was attached to the carriage as before using a lump of Blu Tack.

Once again the RepRap drove the magnet about above the sensors logging the three Hall voltages at each step. This time it moved in a rectangular box 14x14x7 mm in size in 1mm steps in each direction, which is to say a box that contained a 7mm radius cylinder of height 7mm - slightly outside the circle of centres of the sensors.  Readings were only taken within the cylinder.

The system then repeated the movements, attempting to deduce the position of the RepRap carriage from the Hall readings as before.  No sums and differences were used for this; we just used the raw Hall voltages digitised by the Arduino's analog to digital converters to lie in the range [0, 1023]. Here are eight plots of the errors at each height.

Sum and Diff

*Notes:*

- The -1.0 values are not errors; those are just the points outside the cylinder of measured positions.
- The error values are in mm: the error in (*x, y, z*) position.
- The vertical error scales are not the same in each plot; they span the maximum and minimum at each *z* value.
- There are very few errors **inside** the disc of the sensors.
- There is zero error everywhere at *z* = 3mm.

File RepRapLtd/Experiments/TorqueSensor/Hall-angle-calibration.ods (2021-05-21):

angle | A→D reading
-90 | 550 | 3mm gap, magnet 1.5 from centre
-80 | 549
-70 | 544
-60 | 529
-50 | 507
-40 | 459
-30 | 394
-20 | 331
-10 | 288
0 | 264
10 | 255
20 | 257
30 | 272
40 | 308
50 | 364
60 | 423
70 | 473
80 | 503
90 | 522

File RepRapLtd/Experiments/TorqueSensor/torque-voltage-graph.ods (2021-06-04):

grams | A→D | N | V
-400 | 661 | 3.924 | 3.2306940371
-300 | 661 | 2.943 | 3.2306940371
-200 | 661 | 1.962 | 3.2306940371
-100 | 660 | 0.981 | 3.2258064516
0 | 659 | 0 | 3.2209188661
100 | 658 | -0.981 | 3.2160312805
200 | 657 | -1.962 | 3.211143695
300 | 656 | -2.943 | 3.2062561095
400 | 656 | -3.924 | 3.2062561095
300 |  | -2.943 | 0
200 |  | -1.962 | 0
100 |  | -0.981 | 0
0 |  | 0 | 0
-100 |  | 0.981 | 0
-200 |  | 1.962 | 0
-300 |  | 2.943 | 0
-400 |  | 3.924 | 0
-300 |  | 2.943 | 0
-200 |  | 1.962 | 0
-100 |  | 0.981 | 0
0 |  | 0 | 0

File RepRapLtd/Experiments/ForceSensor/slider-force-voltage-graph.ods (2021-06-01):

grams | A→D | N | V
-400 | 498 | 3.924 | 2.4340175953
-300 | 498 | 2.943 | 2.4340175953
-200 | 495 | 1.962 | 2.4193548387
-100 | 489 | 0.981 | 2.3900293255
0 | 485 | 0 | 2.3704789834
100 | 481 | -0.981 | 2.3509286413
200 | 475 | -1.962 | 2.3216031281
300 | 469 | -2.943 | 2.2922776149
400 | 463 | -3.924 | 2.2629521017
300 | 468 | -2.943 | 2.2873900293
200 | 474 | -1.962 | 2.3167155425
100 | 479 | -0.981 | 2.3411534702
0 | 484 | 0 | 2.3655913978
-100 | 488 | 0.981 | 2.38514174
-200 | 492 | 1.962 | 2.4046920821
-300 | 495 | 2.943 | 2.4193548387
-400 | 498 | 3.924 | 2.4340175953
-300 | 498 | 2.943 | 2.4340175953
-200 | 496 | 1.962 | 2.4242424242
-100 | 490 | 0.981 | 2.394916911
0 | 486 | 0 | 2.3753665689

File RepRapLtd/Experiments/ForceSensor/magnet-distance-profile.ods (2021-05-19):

z | v | v | z
0 | 172 | 192 | 1.5
0.5 | 176 | 247 | 2
1 | 181 | 304 | 2.5
1.5 | 192 | 344 | 3
2 | 247 | 374 | 3.5
2.5 | 304 | 399 | 4
3 | 344 | 417 | 4.5
3.5 | 374 | 431 | 5
4 | 399 | 443 | 5.5
4.5 | 417 | 452 | 6
5 | 431 | 460 | 6.5
5.5 | 443 | 465 | 7
6 | 452 | 470 | 7.5
6.5 | 460 | 475 | 8
7 | 465 | 478 | 8.5
7.5 | 470 | 481 | 9
8 | 475 | 484 | 9.5
8.5 | 478 | 486 | 10
9 | 481
9.5 | 484
10 | 486

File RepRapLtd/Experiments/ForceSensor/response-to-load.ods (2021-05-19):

Load (g) | A→D reading | Force(N) | Voltage
-700 | 366 | -6.867 | 1.78885630498534
-600 | 364 | -5.886 | 1.77908113391984
-500 | 373 | -4.905 | 1.82306940371456
-400 | 374 | -3.924 | 1.82795698924731
-300 | 383 | -2.943 | 1.87194525904203
-200 | 389 | -1.962 | 1.90127077223851
-100 | 394 | -0.981 | 1.92570869990225
0 | 399 | 0 | 1.95014662756598
100 | 404 | 0.981 | 1.97458455522972
200 | 408 | 1.962 | 1.9941348973607
300 | 413 | 2.943 | 2.01857282502444
400 | 416 | 3.924 | 2.03323558162268
500 | 421 | 4.905 | 2.05767350928641
600 | 425 | 5.886 | 2.0772238514174
700 | 429 | 6.867 | 2.09677419354839
600 | 426 | 5.886 | 2.08211143695015
500 | 423 | 4.905 | 2.06744868035191
400 | 420 | 3.924 | 2.05278592375367
300 | 416 | 2.943 | 2.03323558162268
200 | 413 | 1.962 | 2.01857282502444
100 | 408 | 0.981 | 1.9941348973607
0 | 403 | 0 | 1.96969696969697
-100 | 399 | -0.981 | 1.95014662756598
-200 | 394 | -1.962 | 1.92570869990225
-300 | 389 | -2.943 | 1.90127077223851
-400 | 383 | -3.924 | 1.87194525904203
-500 | 377 | -4.905 | 1.84261974584555
-600 | 371 | -5.886 | 1.81329423264907
-700 | 365 | -6.867 | 1.78396871945259

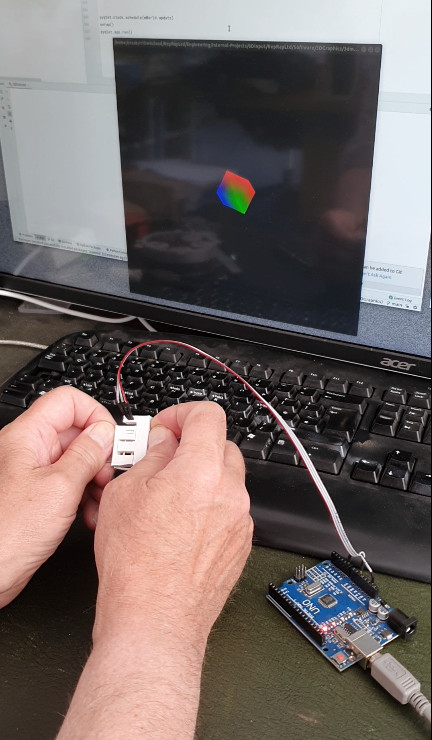
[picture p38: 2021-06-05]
RepRapLtd/Pictures/1D-spacemouse-test.jpg

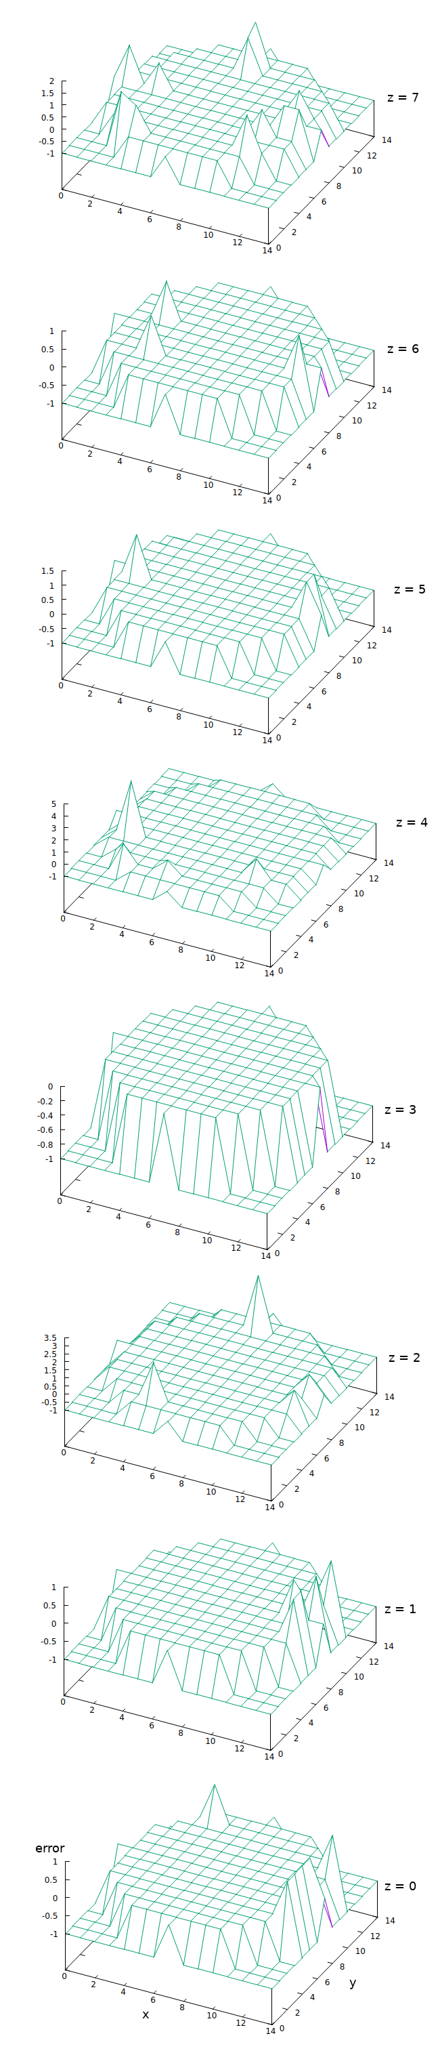
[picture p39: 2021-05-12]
RepRapLtd/Experiments/HallCalibration/errors3D.png

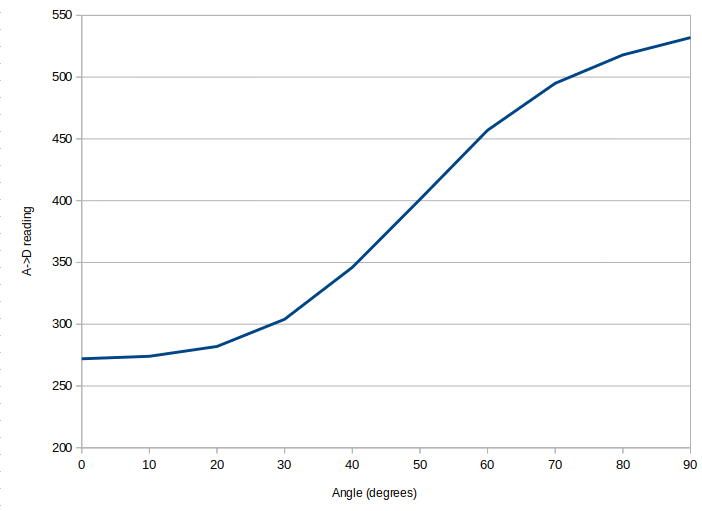
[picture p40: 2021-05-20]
RepRapLtd/Experiments/TorqueSensor/angle-magnet-graph.png

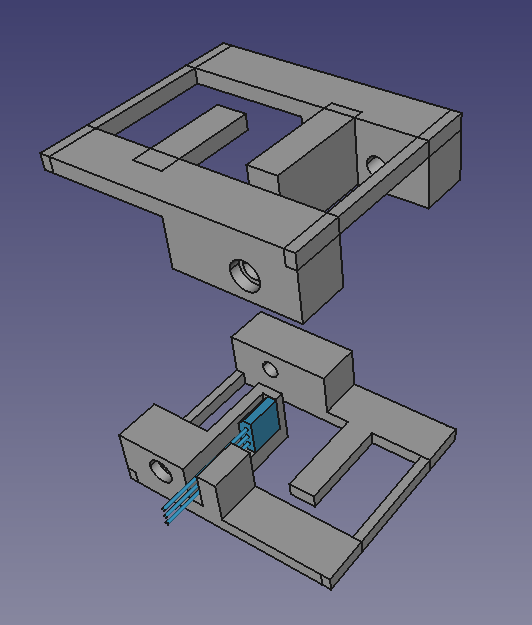
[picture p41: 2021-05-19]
RepRapLtd/Experiments/ForceSensor/sensor-cad.png

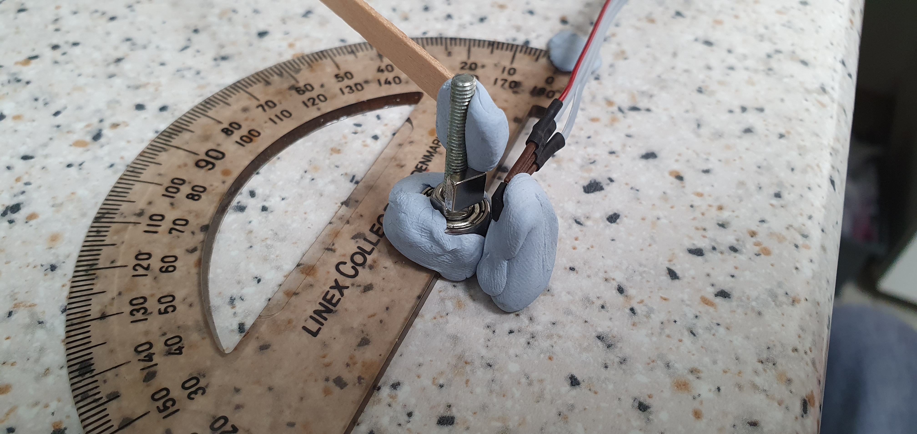
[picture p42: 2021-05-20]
RepRapLtd/Experiments/TorqueSensor/angle-magnet-calibration.jpg

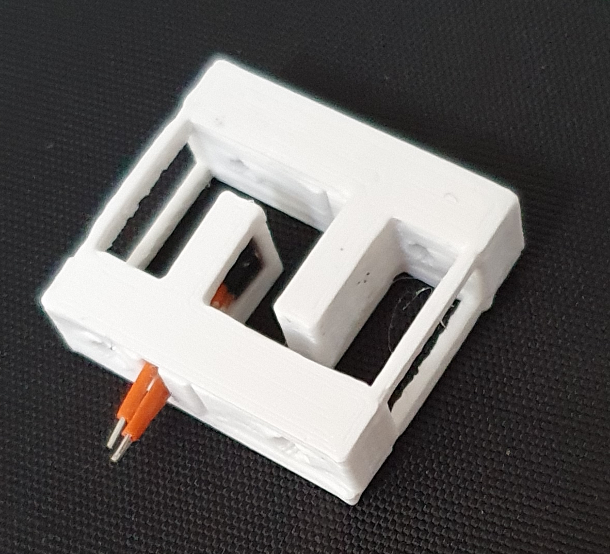
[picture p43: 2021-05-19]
RepRapLtd/Experiments/ForceSensor/sensor.jpg

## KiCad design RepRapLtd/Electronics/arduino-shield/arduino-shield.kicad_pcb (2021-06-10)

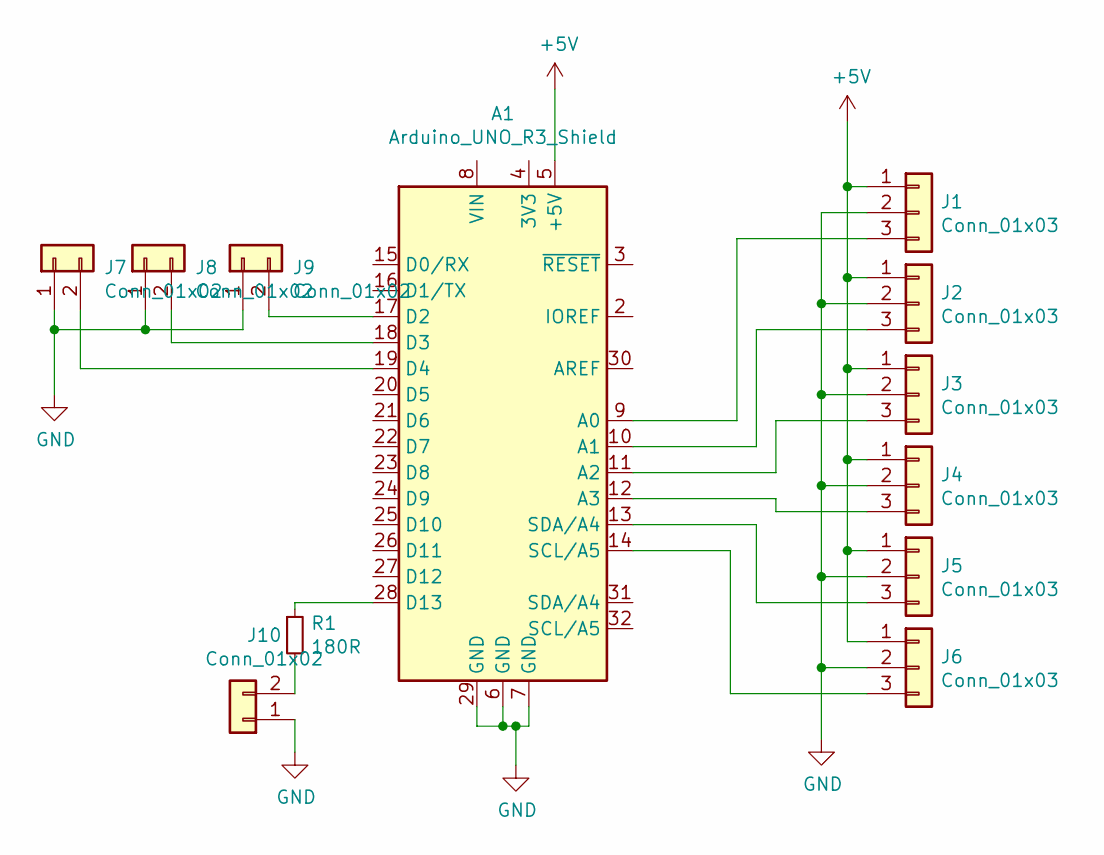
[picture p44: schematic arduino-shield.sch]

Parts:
A1: Arduino_UNO_R3_Shield
J1, J2, J3, J4, J5, J6: Conn_01x03; PinHeader_1x03_P2.54mm_Vertical
J7, J8, J9, J10: Conn_01x02; PinHeader_1x02_P2.54mm_Vertical
R1: 180R; R_0805_2012Metric

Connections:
+5V: A1.5 (+5V), J1.1, J2.1, J3.1, J4.1, J5.1, J6.1
GND: A1.6 (GND), A1.7 (GND), A1.29 (GND), J1.2, J2.2, J3.2, J4.2, J5.2, J6.2, J7.1, J8.1, J9.1, J10.1
unnamed: A1.9 (A0), J1.3
unnamed: A1.10 (A1), J2.3
unnamed: A1.11 (A2), J3.3
unnamed: A1.12 (A3), J4.3
unnamed: A1.13 (SDA/A4), J5.3
unnamed: A1.14 (SCL/A5), J6.3
unnamed: A1.17 (D2), J9.2
unnamed: A1.18 (D3), J8.2
unnamed: A1.19 (D4), J7.2
unnamed: A1.28 (D13), R1.1
unnamed: J10.2, R1.2

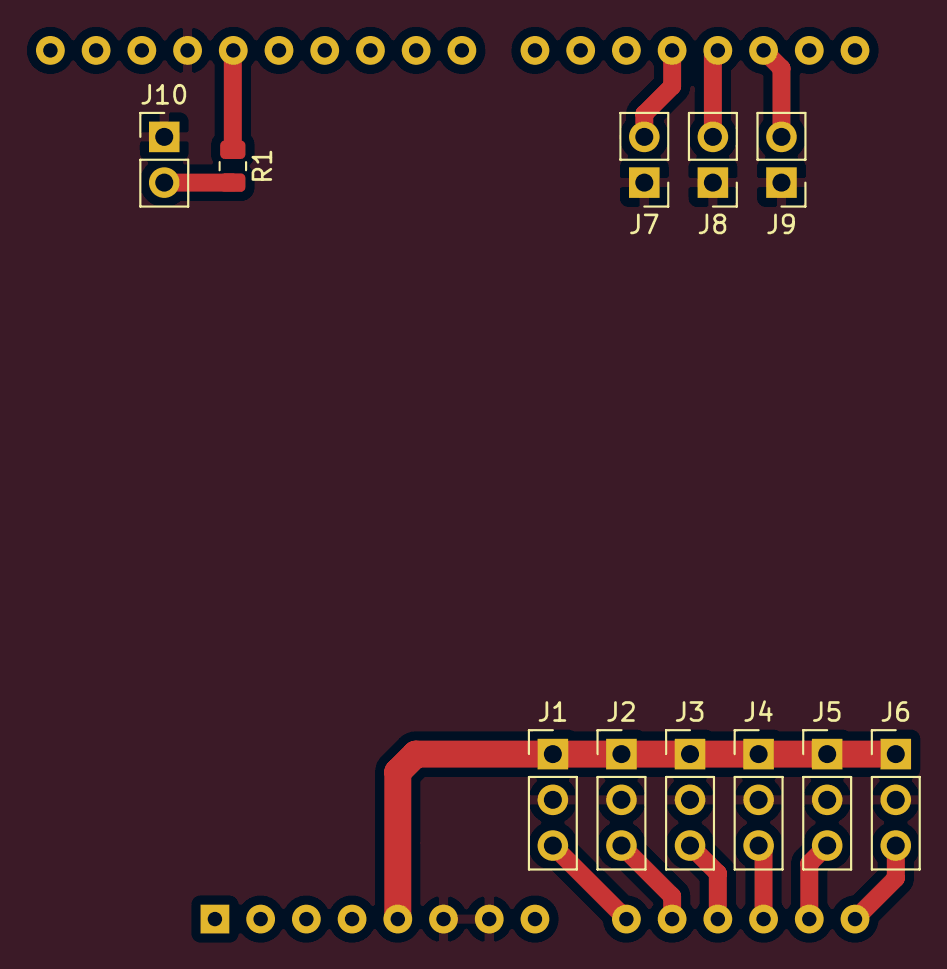
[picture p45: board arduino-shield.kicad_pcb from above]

Board: 2 copper layers, 12 parts (0 on the bottom side), 13 nets.

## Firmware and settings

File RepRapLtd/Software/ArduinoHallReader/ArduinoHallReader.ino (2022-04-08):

/*

Read Hall sensors when prompted and return the voltages.


*/

#define SENSOR_COUNT 1

int hallPins[6] = {A0, A1, A2, A3, A4, A5}; 

int ledPin = 13;

void setup()
{
  for(int i = 0; i < SENSOR_COUNT; i++)
  {
    pinMode(hallPins[i], INPUT);
  }
  pinMode(ledPin, OUTPUT);
  Serial.begin(115200);
}


void loop()
{
  for(int i = 0; i < SENSOR_COUNT; i++)
  {
    int hallReading = analogRead(hallPins[i]);
    Serial.print("Hall ");
    Serial.print(i);
    Serial.print(" reading: ");
    Serial.print(hallReading);
    Serial.print(", (");
    float v = (float)hallReading*5.0/1023.0;
    Serial.print(v);
    Serial.println(" volts).");
  }
  
  delay(500);
}  

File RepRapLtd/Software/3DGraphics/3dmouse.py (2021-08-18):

'''
Test program for the open-source 3D mouse

Move a cube around on the screen.

Adrian Bowyer
RepRap Ltd

4 June 2021

https://reprapltd.com

Licence: GPL

Uses code from https://stackoverflow.com/questions/16263727/3d-cube-didnt-show-correctly-writen-by-pyglet

'''


import sys
import pyglet
from pyglet.gl import *
from pyglet import window
import serial
import re
import time
import numpy as np
import math as maths

arduinoPort = '/dev/ttyUSB0'

axes = ('X', 'Y', 'Z', 'Rx', 'Ry', 'Rz')

# Swap directions if needs be

#sense = np.array([1, 1, 1, 1, 1, 1])
mapping = (0, 1, 2, 3, 4, 5)

wrightMatrix = [
 [-1, -1, -1, -1, 1, 1],
 [1, -1, 1, -1, -1, -1],
 [-1, -1, -1, -1, -1, -1],
 [1, 1, 0, 0, 0, -1],
 [0, 0, 1, 1, -1, 0],
 [-1, -1, 1, -1, -1, 1] ]

class OS3DMouse:

 def __init__(self, port, mouseCalibrationFileName):
  self.usb = serial.Serial(port,115200,timeout=0.1)
  time.sleep(3) # Why so long???
  self.ReZero()
  self.directions = ['+Rx', '-Rx', '+Ry', '-Ry', '+Rz', '-Rz'] #, '+X', '-X', '+Y', '-Y', '+Z', '-Z']
  self.SetVectors(mouseCalibrationFileName)
  print("Mouse initialised: ", self.v0)

 def ReZero(self):
  self.v0 = self.GetHallReadings()[0]

 def GetHallReadings(self):
  self.usb.write(str.encode('6\n'))
  data = self.usb.readline()
  data = str(data.decode('ascii'))
  #print(data)
  data = re.findall('\d+', data)
  reZero = int(data[6])
  if reZero == 0:
   self.ReZero()
  result =  np.zeros(shape=(6))
  for i in range(6):
    result[i] = int(data[mapping[i]])
  return (result, reZero)

 def Movement(self):
  hall = self.GetHallReadings()
  v = np.subtract(hall[0], self.v0)
  v = np.matmul(wrightMatrix, v)
  #print(v)
  #v = self.FindVector(v)
  return (np.array([v[0], v[1], v[2], 0.0, 0.0, 0.0]), hall[1])

 def Sample(self):
  d2 = -1.0
  big2 = 4.0
  mBig = np.array([0.0, 0.0, 0.0, 0.0, 0.0, 0.0])
  while d2 < 2000:
   m = self.Movement()
   d2 = np.sum(m**2)
   if d2 > big2:
    big2 = d2
    mBig = m
  print("Let go...")
  time.sleep(2)
  self.ReZero()
  return mBig

 def Calibrate(self, mouseCalibrationFileName, samples):
  self.directionVectors = []
  print("Mouse calibration. Move in...")
  for direction in self.directions:
   print("---------")
   sum = np.array([0.0, 0.0, 0.0, 0.0, 0.0, 0.0])
   for s in range(samples):
    print(direction)
    sum = np.add(sum, self.Sample())
   sum = np.multiply(sum, 1.0/samples)
   self.directionVectors.append(sum)
  file = open(mouseCalibrationFileName, "w")
  print("Lengths:")
  for v in self.directionVectors:
   length = maths.sqrt(np.inner(v,v))
   print(length)
   file.write(np.array2string(v, max_line_width=1000)[1:-1] + '\n')
  file.close()

 def SetVectors(self, mouseCalibrationFileName):
  file = open(mouseCalibrationFileName, "r")
  self.Rotations = []
  lines = file.readlines()
  for line in lines:
   self.Rotations.append(np.fromstring(line, sep=' '))
  #for r in self.Rotations:
  # print(r)
  self.ROut = [
      np.array([1, 0, 0]),
      np.array([-1, 0, 0]),
      np.array([0, 0, -1]),
      np.array([0, 0, 1]),
      np.array([0, 1, 0]),
      np.array([0, -1, 0])
  ]

 def FindVector(self, v):
  max = -sys.float_info.max
  ip = maths.sqrt(np.inner(v, v))
  if ip < 0.001:
      return np.array([0, 0, 0])
  vN = np.multiply(v, 1.0/ip)
  for r in range(self.Rotations.__len__()):
   ipv = np.inner(vN, self.Rotations[r])
   if ipv > max:
    out = self.ROut[r]
    max = ipv
  return np.multiply(out, ip)


# return a ctype array - GLfloat, GLuint

def vector(type, *args):
    return (type*len(args))(*args)


class model:
    def __init__(self, vertices, colorMatrix, index, mouse):
        self.vertices = vector(GLfloat, *vertices)
        self.colourMatrix = vector(GLfloat, *colorMatrix)
        self.index = vector(GLuint, *index)
        self.Recentre()
        self.mouse = mouse

    def update(self):
        mMove = self.mouse.Movement()
        move = mMove[0]
        a = np.multiply(np.array([move[0], move[1], move[2]]), 1.0/20.0)
        p = np.multiply(np.array([move[3], move[4], move[5]]), 1.0/60.0)
        self.angle = np.remainder(np.add(self.angle, a), 360)
        self.position = np.add(self.position, p)
        if mMove[1] == 0:
         self.Recentre()


    def Recentre(self):
        self.angle = np.array([0.0, 0.0, 0.0])
        self.position = np.array([0.0, 0.0, 0.0])

    def draw(self):
        glMatrixMode(GL_MODELVIEW)
        glLoadIdentity()

        glRotatef(self.angle[0], 1, 0, 0)
        glRotatef(self.angle[1], 0, 1, 0)
        glRotatef(self.angle[2], 0, 0, 1)
        glTranslatef(self.position[0], self.position[1], self.position[2])

        glEnableClientState(GL_VERTEX_ARRAY)
        glEnableClientState(GL_COLOR_ARRAY)

        glColorPointer(3, GL_FLOAT, 0, self.colourMatrix)
        glVertexPointer(3, GL_FLOAT, 0, self.vertices)
        glDrawElements(GL_QUADS, len(self.index), GL_UNSIGNED_INT, self.index)

        glDisableClientState(GL_COLOR_ARRAY)
        glDisableClientState(GL_VERTEX_ARRAY)



class world:
    def __init__(self):
        self.element = []
        self.callCount = 0

    def update(self, dt):
        for obj in self.element:
            obj.update()

    def addModel(self, model):
        self.element.append(model)

    def draw(self):
        self.callCount += 1
        for obj in self.element:
            #if self.callCount >= 200:
            #    obj.Recentre()
            #    self.callCount = 0
            obj.draw()


def setup():
    # look for GL_DEPTH_BUFFER_BIT
    glEnable(GL_DEPTH_TEST)


cube = (
    3, 3, 3, #0
    -3, 3, 3, #1
    -3, -3, 3, #2
    3, -3, 3, #3
    3, 3, -3, #4
    -3, 3, -3, #5
    -3, -3, -3, #6
    3, -3, -3 #7
)


colour = (
    1, 0, 0,
    1, 0, 0,
    1, 0, 0,
    1, 0, 0,
    0, 1, 0,
    0, 1, 0,
    0, 0, 1,
    0, 0, 1
)

index = (
    0, 1, 2, 3, # front face
    0, 4, 5, 1, # top face
    4, 0, 3, 7, # right face
    1, 5, 6, 2, # left face
    3, 2, 6, 7, # bottom face
    4, 7, 6, 5  #back face
)





mouse = OS3DMouse(arduinoPort, "mouseCalibration.txt")
#mouse.Calibrate("mouseCalibration.txt", 5)



win = window.Window(fullscreen=False, vsync=True, resizable=True, height=600, width=600)
mWorld = world()
obj = model(cube, colour, index, mouse)
mWorld.addModel(obj)

@win.event
def on_resize(width, height):
    glViewport(0, 0, width, height)
    glMatrixMode(GL_PROJECTION)
    glLoadIdentity()
    glOrtho(-10, 10, -10, 10, -10, 10)
    glMatrixMode(GL_MODELVIEW)
    return pyglet.event.EVENT_HANDLED

@win.event
def on_draw():
    glClearColor(0.2, 0.2, 0.2, 0.8)
    glClear(GL_COLOR_BUFFER_BIT | GL_DEPTH_BUFFER_BIT)
    mWorld.draw()


pyglet.clock.schedule(mWorld.update)
setup()
pyglet.app.run()

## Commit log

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2021-05-01 Mockup of capacative zones for pan and twist degrees of freedom
    This is just a mockup for comment, not a working board. Enclosed copper
    areas should be filled and connected to appropriate nets.
    As proposed https://twitter.com/databasescaling/status/1388295587062243331
    The boards in the stack would all be the same but with different parts
    wired up.
    A stack of two boards could provide the two pan degrees of freedom in X and
    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
    [capsense.kicad_pcb]
2021-05-01 Added most complete concept model created to investigate feasibility of printing entire joystick assembly. FreeCAD project requires FreeCAD 0.19 or newer with Assembly 4 and Fasteners add ons. The as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
    [6DInput_MagneticEncoder.FCStd, AS5247UAdapterBoard.FCStd, Bearing603Open.FCStd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]
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2021-05-03 Small Python program and Arduino program written to talk to each other. Tested with logging OH49E Hall sensor voltages. Seems to work...
2021-05-04 Python program now controls both RepRap and Arduino. Next step: set it up to map the space above the Hall sensors.
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2021-05-05 First calibration results.
    [hall-calibration-graph.ods, hall-calibration0.csv, hall-calibration1.csv]
2021-05-06 First full calibration, with errors.
    [hall-calibration-graph.ods, hall-calibration0.csv, hall-calibration1.csv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]
2021-05-07 Results of first Hall effect experiment written up.
    [hall-calibration0.csv, hall-calibration1.csv, xzErrors.csv]
2021-05-10 Experiment with sensors closer together...
    [hall-calibration0.csv, hall-calibration1.csv, xzErrors.csv]
2021-05-11 First results of 3D magnet/Hall position tracking experiments.
    [Hall-ring-experiment-holder.FCStd, Hall-ring.stl]
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2021-05-18 WIP on force and displacement sensor...
    [calibration-jig.stl, force-displacement-sensor-V2.FCStd, force-displacement-sensor-hall.stl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]
2021-05-19 Force sensor design and experimental results on it.
    [force-displacement-sensor-V2.FCStd, magnet-distance-profile.ods, response-to-load.ods]
2021-05-20 Reduced force sensor gap to 3mm.
    [force-displacement-sensor-V2.FCStd, force-displacement-sensor-hall.stl, force-displacement-sensor-magnet.stl]
2021-05-20 Calibration jig updated with correct wire hole.
    [force-displacement-sensor-V2.FCStd]
2021-05-20 Starting work on a torque sensor...
    [Hall-angle-calibration.ods, magnet-distance-profile.ods, response-to-load.ods]
2021-05-20 Consistent rename.
    [Hall-angle-calibration.ods]
2021-05-21 Small correction to force sensor design.
    [force-displacement-sensor-V2.FCStd, force-displacement-sensor-hall.stl, force-displacement-sensor-magnet.stl]
2021-05-21 W.I.P. on the torque sensor.
    [Hall-angle-calibration.ods, torque-sensor.FCStd, torque-sensor.stl]
2021-05-21 Started on the octahedron design.
    [octahedron-design.FCStd]
2021-05-22 Torque sensor WIP...
    [torque-sensor.FCStd, torque-sensor.stl, torque-spring.stl]
2021-05-24 New design for force sensor.
    [force-hall.stl, force-magnet.stl, force-sensor.FCStd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]
2021-05-24 Force sensor WIP
    [force-sensor.FCStd]
2021-05-28 New force sensor design.
    [calibration-jig.FCStd, calibration-jig.stl, force-displacement-sensor-V2.FCStd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]
2021-05-31 New (improved?) torque sensor design. (Prints in one shot.)
    [force-sensor-V1.FCStd, torque-sensor-V1.FCStd, torque-sensor-V2.FCStd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]
2021-06-01 Small corrections to the torque sensor design.
    [torque-sensor-V2.FCStd, torque-sensor.stl]
2021-06-01 Calibration of latest force sensor design.
    [slider-force-voltage-graph.ods, torque-sensor-V2.FCStd, torque-sensor.stl]
2021-06-01 New torque sensor mods.
    [torque-sensor-V2.FCStd, torque-sensor.stl]
2021-06-04 Python 3D test program added. Works in 1D ...
    [torque-voltage-graph.ods]
2021-06-05 Results of 1D animation experiment added.
    [force-sensor-V1.FCStd]
2021-06-07 Added 3-sensor video. Arduino shield design started.
    [arduino-shield.kicad_pcb, arduino-shield.sch]
2021-06-07 Added button connectors and LED connector to the Arduino shield.
    [arduino-shield.kicad_pcb, arduino-shield.sch]
2021-06-08 2D joystick added.
    Python test program improved.
    [2D-joystick-V1.FCStd, joystick-body.stl, joystick-lever.stl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]
2021-06-09 C++ and Python code updated to allow Python to request number of analogue reading from Hall sensors to be sent. Means the Arduino doesn't have to be reflashed every time the number of sensors changes.
    [3dmouse.py, ArduinoHallReader.ino]
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2021-06-09 New torque sensor design.
    [torque-hall.stl, torque-magnet.stl, torque-sensor-V2.FCStd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]
2021-06-10 3-axis integrated design for all torques added.
    [XYZ-joystick-V1.FCStd, XYZ-joystick-lever.stl, XYZ-joystick-twist-spring.stl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]
2021-06-11 XYZ joystick working...
    [XYZ-joystick-V1.FCStd]
2021-06-11 README update
    [steel-disc-mass.ods]
2021-06-11 6D-cones idea designed provisionally.
    [6D-cones-calibration.stl, 6D-cones-hall.stl, 6D-cones-magnet.stl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]
2021-06-14 First design for complete OS3Dmouse. This is not how to do it. But it's easy to get to from here and it might work...
    [OS3Dmouse-V1.FCStd, OS3Dmouse-XY-link.stl, OS3Dmouse-YZ-link.stl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]
2021-06-15 Yet another design started...
    [6DOF-disc.FCStd]
2021-06-21 First simple disc design.
    [6DOF-disc.FCStd, 6DoF-disc-base.stl, 6DoF-disc-handle.stl]
2021-06-25 Started coding for the disc design.
    [6DOF-disc.FCStd]
2021-06-29 Dud experiment and next stage added.
    [6DOF-disc.FCStd]
2021-07-16 Latest disc design.
    [6DOF-disc.FCStd, 6DoF-disc-base.stl, 6DoF-disc-handle.stl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]
2021-07-28 Added silicone spring. Updated base design to clamp rather than glue Hall sensors.
    [6DOF-disc.FCStd, 6DoF-disc-base.stl, silicone-spring-mould.FCStd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]
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2021-08-02 More work on the 6D disc design and software.
    [6DOF-disc.FCStd, 6DoF-disc-base.stl, 6DoF-disc-handle.stl]
2021-08-13 Improved disc design. Spring mould improved also.
    [6DOF-disc-wright-base.stl, 6DOF-disc-wright-handle.stl, 6DOF-disc-wright.FCStd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]
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2022-04-08 Restored Arduino hall reading program.
    [SM Base-Base.stl, SM Base.FCStd]
